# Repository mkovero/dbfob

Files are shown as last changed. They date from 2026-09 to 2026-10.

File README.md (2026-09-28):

# dbfob

**A dirt-cheap keyfob that tells you how loud it is — and how long your ears can take it.**

Press the button, look at the colour. Green means you're fine. Red means leave.

dbfob is an open-hardware sound level indicator sized for a keyring. It exists because nobody pulls out a phone on a dark dance floor to run a sound level meter, but everybody can glance at an LED. It is meant to be cheap enough that a venue, a festival or a hearing-health campaign can hand them out at the door next to the free earplugs.

## Status

**Rev A prototype, not yet validated on hardware.**

| Part | State |
|---|---|
| [Hardware](hardware/README.md) | 5 assembled boards ordered from JLCPCB, 2026-09-27. DRC-clean, placement verified against JLC's footprints. |
| [Firmware](firmware/README.md) | Builds for the CH32V003 and passes the host DSP tests (A-weighting within 0.02 dB, 50 Hz–8 kHz). Not yet run on a board. |
| [Case](hardware/case/README.md) | Two-shell SLA case modelled, fit-checked and exported. Not yet printed. |

Next steps are bring-up and calibration against a reference meter. See [Next](#next).

## How it works

1. Press the button. The fob wakes from standby.
2. A PDM MEMS microphone samples the room for 3 seconds.
3. The firmware A-weights the signal and computes the equivalent continuous level (LAeq).
4. A four-LED bar shows two verdicts for 2 seconds: a steady LED for a bare ear and a blinking LED for ear plugs. See below.

The LEDs are deliberately dim, since clubs are dark, and they auto-dim using one LED as a light sensor. Each reading is also printed on a UART pad for calibration.

### Colour bands

The bands are **levels at the ear**, not safety guarantees. The times are the full daily allowance at that level under the NIOSH / EU occupational curve, `T = 8 h × 2^((85 − L)/3)`: 85 dBA for 8 hours, 3 dB exchange rate.

| Colour | At the ear (dBA) | Daily allowance at that level |
|---|---|---|
| Green | ≤ 83 | Below the 85 dBA / 8 h limit |
| Yellow | 84–90 | About 10 h down to 2.5 h |
| Orange | 91–96 | About 2 h down to 40 min |
| Red | ≥ 97 | Under about 30 min |

A 3-second spot reading describes the room right now, not your night. The allowance is for a whole day starting from zero, so anything you've already heard today uses part of it. Green means this level is below the limit, not that the whole night is safe.

### Two LEDs, two questions

Every reading answers two questions at once, so there is no mode to set or forget:

- **Steady LED: what reaches a bare ear.** This is the room level itself: measured, with no assumptions.
- **Blinking LED: what would reach the ear through plugs that really give 12 dB.** This is a conditional estimate, not a measurement and not a safety verdict. The fob cannot know how well your plugs fit. Foam plugs claim 30+ dB on the box, but inserted in a hurry by someone who's had a drink, 10–15 dB is realistic. A badly seated plug can give much less. Individual fit testing is the only way to know your own attenuation, and NIOSH recommends it.

In a 100 dBA room, red glows steady and yellow blinks: you're in the red, and well-fitted plugs could bring you to yellow. When both answers are the same, only one steady LED lights.

The obvious alternative was a mode switch, but either default misleads someone. Assume plugs, and people without them get a falsely reassuring answer. Assume no plugs, and people who do wear them always see red, so the device looks useless to the people doing the right thing. Showing both removes the default, and the gap between the two LEDs is itself the argument for plugs.

### Modes

- **Single press — spot check.** Measures the current level and shows a colour for a few seconds. This is the mode that is always trustworthy, because you are holding the device out in front of you.
- **Double press — dosimeter.** *Not implemented; an idea for later.* The fob would sample for a couple of seconds every minute and accumulate dose. A single press would then show dose as a fraction of the daily allowance, bare ear and with plugs the same way.

The catch is that a keyfob lives in a pocket. A pocket reads 10–20 dB low with the high end rolled off, so an unsupervised dose would be a comforting lie. Dosimeter mode would need to detect occlusion from the spectrum, since the high-band to low-band energy ratio collapses in a pocket. It would refuse to count those samples and flag the dose as incomplete. For a real dosimeter, clip it to your shoulder.

## Hardware

No radio, no display, no app. The design goal was **under €2 all-in**. The rev A parts come to about $1.85 per board at 1,000 units. A 130 dB-capable mic alone is about €1.2, so sub-€1 is out unless mic prices drop.

| Block | Part | Why |
|---|---|---|
| Microphone | Infineon **IM69D130**, PDM | **Acoustic overload ≥ 130 dB SPL.** Hobby-favourite digital mics clip at about 120 dB, which a club sub stack exceeds. It is digital, with ±1 dB sensitivity, so a batch can be calibrated rather than each unit, and the reading doesn't drift with battery voltage. |
| MCU | WCH **CH32V003F4P6** | The CH32V002/V006 are pin-compatible drop-ins, but were out of stock. The V003 has no hardware multiplier (handled in firmware) and needs at least 2.7 V. |
| LEDs | 4 × 0603 low-Vf LEDs as a bar: yellow-green, yellow, orange, red | InGaN green and blue LEDs need about 3 V and fade on a coin cell. The bar position also encodes the level for colour-blind users. D4 doubles as the light sensor. |
| Power | CR2032 in a Keystone 3034 | Standby is about 7.6 µA, so an idle fob lasts about 3 years. The mic is powered only while measuring. |
| Input | 1 × tactile switch | Wakes the MCU. |
| Case | 3D-printed two-part shell, one M2 screw | Mic and LEDs at one end, keyring at the other. |

Background and trade-offs:
- The part comparison is in [docs/mic-mcu-options.md](docs/mic-mcu-options.md).
- An independent hardware audit, with the response to each finding, is in [docs/hardware-audit-2026-09-27.md](docs/hardware-audit-2026-09-27.md).

### Accuracy

Cheap MEMS parts are ±3 dB sensitivity; better ones are ±1 dB and factory-calibrated. Either is fine for four colour bands. The real uncertainty in this device is placement (held out vs. cupped in a hand vs. in a pocket) and earplug fit, not the microphone. Design effort goes into making "not trustworthy" visible, not into the last dB.

### Calibration

A 94 dB pistonphone won't couple to a MEMS port. Calibrate by substitution instead: place the fob next to a measurement mic in a room with pink noise at a few levels, note the offset, store it in flash. Also characterise the offset when hand-held vs. on a table, since that is how people will actually use it.

## Repository layout

```
hardware/        KiCad project, generated from the tables in hardware/tools/ (schematic, PCB, JLC outputs)
hardware/case/   FreeCAD case script, STEP/STL for printing, board geometry it is built from
firmware/        CH32V003 firmware on ch32fun: PDM capture, A-weighting, LAeq, LEDs, standby; host tests
docs/            part selection, hardware audit
```

## Next

- [ ] Bring-up on rev A: power, programming, mic capture, CPU load, standby current. See [firmware/README.md](firmware/README.md#bring-up-checklist).
- [ ] Calibrate against a reference meter, in the case: the level offset and the hand-held offset.
- [ ] Qualify the battery: the supply voltage under load across cell charge and temperature, then set the cutoff.
- [ ] Print the case and check the tolerances, the button flexure and the mic seal.
- [ ] A calibration procedure anyone can repeat with a known-good meter.
- [ ] Rev B board: centre the mic port, add UART RX for a bootloader, CH32V002/V006 if in stock, possibly a power latch for shelf life.
- [ ] Dosimeter mode with occlusion detection.
- [ ] Get a batch into a venue and see if people use them.

## Non-goals

- Bluetooth, apps, logging to the cloud. The point is that nothing needs to be looked at except one LED.
- Certified measurement accuracy. This is a warning light, not a Class 1 meter.

## Why

Hearing damage is cumulative and irreversible, and the people most at risk are the ones who go out the most. Earplugs are cheap and effective, but people don't put them in unless they have a reason to. A colour that says "you are in the red" is a reason.

## License

Hardware: CERN-OHL-P. Firmware: MIT. Documentation: CC BY 4.0.

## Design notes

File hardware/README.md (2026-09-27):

# dbfob hardware, rev A

30 × 52.5 mm, 2 layers, all parts on the top side. It is powered by a CR2032, the only input is one button, and the only output is a four-LED bar. Part choices are explained in [../docs/mic-mcu-options.md](../docs/mic-mcu-options.md).

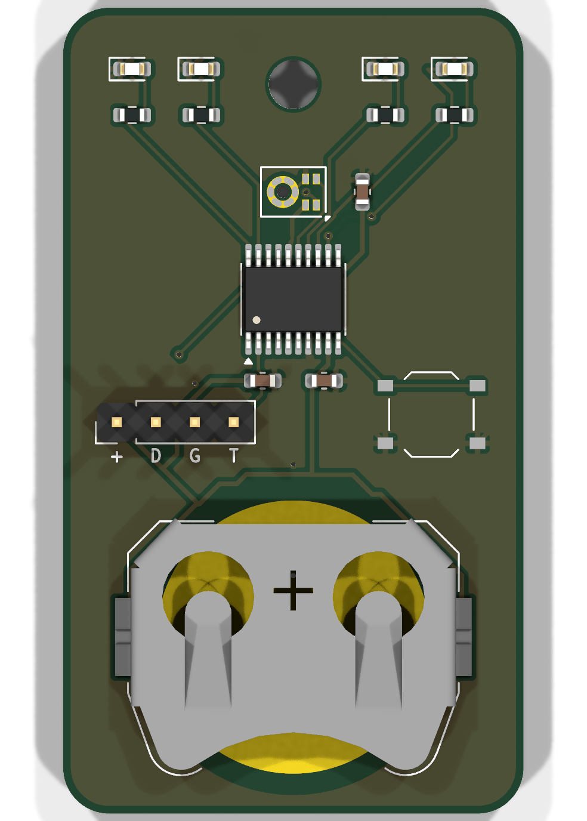
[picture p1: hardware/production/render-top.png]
top render


## Everything regenerates

The procedure follows `studer-vca/etofab.md`. The tables in `tools/gen_sch.py` are the only source; do not hand-edit the sheet or the board.

```sh
python3 hardware/tools/gen_sch.py    # tables -> dbfob.kicad_sch
python3 hardware/tools/make_pcb.py   # schematic -> placed, routed, poured, DRC'd board (~30 s)
python3 hardware/tools/fab.py        # board -> production/
```

These need KiCad 10 (`kicad-cli` and the `pcbnew` Python module) and [KiCadRoutingTools](https://github.com/drandyhaas/KiCadRoutingTools) at `/home/mui/src/KicadRoutingTools` (override with `KRT=`).

State at commit:
- **ERC:** clean, apart from KiCad's library-table warnings and one expected `pin_to_pin` warning. That warning comes from the PWR_FLAG on MIC_VDD, which is powered by a GPIO.
- **DRC:** 0 errors, 0 warnings, 0 unconnected, 0 schematic-parity issues.
- **Reproducibility:** two runs give byte-identical boards.

## Circuit

| U1 pin | Port | Net | Function |
|---|---|---|---|
| 15 | PC5 | MIC_CLK | SPI1 SCK, the PDM clock: 1.5 MHz (see [clock plan](#pdm-clock-plan)) |
| 17 | PC7 | MIC_DATA | SPI1 MISO, the PDM data. MK1 SELECT is tied to GND |
| 16 | PC6 | MIC_VDD | GPIO push-pull. The mic is powered only while measuring (≈0.6 mA at 1.5 MHz). Discard audio until 50 ms after VDD *and* the clock are both running |
| 20 | PD3 | LED_G | TIM2_CH2, D1 yellow-green |
| 19 | PD2 | LED_Y | TIM1_CH1, D2 yellow |
| 14 | PC4 | LED_O | TIM1_CH4, D3 orange |
| 13 | PC3 | LED_R | TIM1_CH3, D4 red (anode side) |
| 12 | PC2 | LED_R_K | D4 cathode: drive low to light it; reverse-bias and time the decay to sense ambient light |
| 10 | PC0 | BTN | SW1 to GND. Use the internal pull-up; EXTI wakes the MCU from standby |
| 18 | PD1 | SWIO | Programming (WCH-LinkE) |
| 2 | PD5 | TX | USART1 TX: prints dB readings during calibration |

**LEDs.** The bar is deliberately dim: a club is dark and the fob should not light up the room. The resistors cap the current at about 0.45 mA (2.2 kΩ), or about 1 mA for the dimmer yellow-green (1 kΩ). Firmware uses PWM to go well below that indoors and shows the result for about 2 s.
- **Ambient light sensing.** D4's cathode is on PC2 rather than GND, so the red LED doubles as a light sensor. Reverse-bias it (PC3 low, PC2 high), switch PC2 to input, and time how long it takes to read low. Fast means bright, which lets the firmware tell a dark room from daylight.
- **Why these LEDs.** All four are low-Vf AlInGaP/GaP types (1.6–2.6 V), so every colour still lights near the end of the cell's life; InGaN green and blue LEDs need about 3 V.
- **Order.** The bar runs G Y · O R from left to right. The position of the lit LED also encodes the level, so the bar works for colour-blind users.

**J1** is four 2.54 mm pads: `+ D G T` = VBAT, SWIO, GND, TX. Fit a header by hand, or hold pogo pins against it. It is not assembled.

**Mic port.** MK1 is a bottom-port mic, so it hears through the 0.8 mm hole to the **back** of the board (marked MIC). Don't cover it, and give the case an opening there.

**Coin cell.** The Keystone 3034 uses a PCB pad as the − contact. The cell's + can wraps around onto the − face at the rim, so the top layer has no copper in the ring under the rim: only solder mask would stand between + and a GND pour. The − pad reaches ground through four vias inside the pad. There is no reverse-polarity protection; the holder only accepts the cell one way round.

## MCU: fitted with a CH32V003

The CH32V002 and CH32V006 had **zero stock at JLC/LCSC on 2026-09-27**, so the BOM carries the pin-compatible **CH32V003F4P6** (C5187096, 1035 in stock). The TSSOP-20 pinout is identical: it was checked against table 2-1 of the V002 datasheet. When stock returns, change the LCSC number in `gen_sch.py`. The board stays the same.

The V003 costs the project two things:
- **No hardware multiply.** Build the firmware for `rv32ec`, which runs on all three chips. The biquads cost more cycles but fit easily at 48 MHz.
- **Minimum supply of 2.7 V instead of 2.0 V.** How much of the cell that costs is **not known yet**. See [Power](#power-unqualified).

## PDM clock plan

The IM69D130 is specified only in four clock bands: 0.40–0.95, 1.05–1.9, 2.1–2.65 and 2.9–3.3 MHz (datasheet table 4). The CH32's SPI clock is its bus clock divided by a power of two, 2 to 256. The earlier plan of 1.024 MHz fell between two bands and could not be generated anyway.

The plan is **1.5 MHz**: 48 MHz / 32, or 24 MHz / 16 if the core runs at 24 MHz to save current. Decimating by 64 gives **23,437.5 samples/s**, so the audio bandwidth reaches about 11.7 kHz. The decimator and the A-weighting biquads are designed for exactly that rate. The mic's startup time (20 ms to ±0.5 dB, 50 ms to ±0.2 dB) counts from when both VDD and the clock are present (table 5).

Still to show on hardware: the V003 has no multiplier and 2 KB of RAM, so it must keep up with 1.5 Mbit/s of PDM continuously.

## Power (unqualified)

These are datasheet estimates. No board current has been measured yet.

- **Active.** The CH32V003 draws about 4–6 mA at 48 MHz (HSI), and the mic about 0.6 mA. A CR2032's internal resistance rises as it discharges and as it gets cold. With 50 Ω, 6 mA pulls a 3.0 V cell down to the V003's 2.7 V minimum, and the 10 µF cap bridges that for only about half a millisecond, not a 3 s measurement. The V003 can also run below its guaranteed range before its reset threshold trips.
  - Firmware runs the measurement at 24 MHz, and measures VDD under load against the internal reference throughout.
  - Below a cutoff with margin, it shows an explicit **invalid / battery** pattern instead of a level.
  - Qualification: log minimum VDD through acquisition and display, across cell state of charge and temperature, with real cells.
  - If usable capacity is too low, reconsider the MCU or supply in rev B.
- **Standby.** The V003's typical standby current is 7.6 µA (LSI off), about 67 mAh per year. That limits an idle fob to roughly 3 years on a 220 mAh cell, much more than self-discharge does. The CH32V002 would be worse, at 17.5 µA. The mic uses no standby current because it is unpowered. If shelf life matters, rev B could add a button-triggered power latch, so standby becomes a switch's leakage.

## Programming

J1 pin 1 is wired directly to the cell's + terminal. **Take the cell out before connecting a programmer or powering a board for calibration.** A WCH-LinkE supplying 3.3 V into an installed CR2032 would charge it, and Energizer allows 1 µA of reverse current at most. Put the cell back in afterwards. The legend on the back of the board says the same. A fixture should enforce this order, for example by physically blocking the holder. A board powered from its cell must be programmed with the programmer's supply pin unconnected.

## Ordering at JLCPCB

Upload `production/dbfob-gerbers.zip`, then for assembly `production/bom_jlc.csv` and `production/cpl_jlc.csv`.

- **PCB:** 2 layers, 1.6 mm, any colour, tented vias.
- **Finish: lead-free HASL for prototypes, ENIG for production.** At 5 boards ENIG took the PCBA order from €6.46 to €22 (2026-09-27) for little gain here. The mic's 0.45 mm pads on a 0.7 mm pitch solder fine on HASL, and the holder's spring presses the cell onto the slightly domed − pad. Choose lead-free rather than leaded HASL: these get carried on keyrings. At volume the ENIG premium per board shrinks, and its flat, non-oxidising battery contact becomes worth it.
- **Assembly:** economic, top side only, 15 placements, 12 BOM lines. J1 is not placed. Board cleaning: no.
- **Tooling holes.** On a 1×1 board without edge rails, JLC drills its tooling holes into the board itself, and ground copper covers almost all of both sides. In the placement review, check they stay clear of:
  - the cell's − pad and the copper-free ring around it,
  - the traces between the LEDs and U1,
  - the mic hole.

  If they don't, order a 1×1 panel with edge rails instead.
- **Extended parts:** U1, MK1, BT1, D1, D2 and D3 are extended. Each carries JLC's flat per-part setup fee regardless of quantity (etofab.md §7).
- **Low-stock lines to check before paying:**
  - MK1 IM69D130 (C536262): 614 in stock, about $3 each at small quantities.
  - D3 orange KT-0603O (C111340): 3979 in stock.
- **Placement is verified against JLC's own footprints.** JLC places each part with the EasyEDA footprint of its LCSC number. `tools/check_cpl.py` puts those footprints where the CPL says and checks three things: every pad lands on the KiCad pad of the same pin, MK1's port lands on the sound hole, and BT1's opening faces the board edge. `fab.py` refuses to finish if any check fails. The corrections are in `JLC_FRAME` in `fab.py`:
  - U1: +270°.
  - MK1: +90°, and the CPL point moves 0.13 mm, because EasyEDA's origin is not the package centre.
  - BT1: +180°. Its pads are symmetric but the opening is not.
  - LEDs: none. The cathode is on the left in both libraries, even though the pad numbers differ.

  Rev A's first CPL had MK1 turned 90° and BT1 backwards; this check is what caught it. Still glance at JLC's preview before paying.
- **MK1 is a MEMS mic with an open port.** Make sure the board is not water-washed after reflow.

## Microphone supply

On 2026-09-27, DigiKey lists IM69D130V01XTSA1 as *Active*. The [hardware audit](../docs/hardware-audit-2026-09-27.md) reports that Infineon marks this ordering code *not for new design*; I could not confirm that on Infineon's site. Either way, rev A is a prototype and limited-build decision. Before repeat production, confirm the status and either secure supply or move to a replacement. The TDK T5818 is 1.65–3.63 V, ±1 dB and 135 dB AOP in its 2.0–3.3 MHz mode. A replacement means revalidating the footprint, clock plan and signal processing.

## Release gates

`make_pcb.py` exits nonzero on any DRC error, open net, schematic-parity issue, or DRC warning other than the missing-library-table one. `fab.py` refuses to write anything unless ERC, DRC and parity are clean. The only exceptions are the library-table warnings and the documented MIC_VDD PWR_FLAG. It builds every output in `production.staging/`, runs `check_cpl.py` there, and only then replaces `production/`. `check_cpl.py` also requires the BOM and CPL designator sets to match, each designator to appear once, and each CPL layer to match the board side.

## Not verified yet

This is rev A and no hardware exists. Open items before calling it done:
- Continuous 1.5 MHz PDM acquisition and decimation on the V003 (no multiplier, 2 KB RAM).
- Weighted level accuracy across frequency, SPL, hand placement and battery state, and behaviour on overload.
- The mic's current when powered from a GPIO.
- Standby current, VDD under load across cell state (see Power), and so usable capacity and shelf life.
- Mechanical: cell insertion, removal and retention, keyring abrasion, sound-port occlusion in the hand and in the final case. The render has no 3D model for the mic.
- The hand-held level offset.

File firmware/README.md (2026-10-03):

# dbfob firmware

Firmware for the rev A board: a CH32V003F4P6 with an IM69D130 PDM mic. It is built on [ch32fun](https://github.com/cnlohr/ch32fun), included as a submodule.

**Status: builds and passes host tests, but has never run on hardware.** Every constant marked `BRINGUP` in `dbfob.c` is an estimate that must be set on the bench.

## What it does

1. The board sits in standby until the button (PC0) is pressed.
2. It senses ambient light through D4 to set LED brightness.
3. It powers the mic from PC6 and clocks it at **1.5 MHz**: SPI1 SCK on PC5, 48 MHz / 32.
4. It captures PDM from MISO (PC7) by DMA into a 128-byte ring. Each 64-byte half is processed in the DMA interrupt.
5. It discards 150 ms of mic start-up and filter settling, then integrates **3 s** of A-weighted energy. VDD is read under load every 50 ms throughout.
6. It shows two verdicts for 2 s (see the [top-level README](../README.md#colour-bands)):
   - **Steady LED:** bare ear.
   - **Blinking LED:** with plugs giving 12 dB.
   - **Alternating G/R:** invalid reading (battery below the cutoff, no samples, or DMA overrun).
7. It prints one line per reading on USART1 TX (PD5, J1 pin 4 "T", 115200 8N1), then returns to standby.

Example output line:

```
dbfob dBA=94.2 dBFS=-35.7 n=70313 peak=1873 pcm_peak=1510 overload=0 vdd_idle=3012 vdd_min=2941 light_us=38210 duty=112 cpu=31% overruns=0
```

## Signal chain

Everything below is in `src/dsp.c`. The same file is compiled into the firmware and into the host test.

| Stage | Rate | Implementation |
|---|---|---|
| PDM in | 1.5 Mbit/s | SPI RX-only master, CPOL 0 / CPHA 0 (SELECT = GND: DATA valid while CLK low, sampled on the rising edge) |
| CIC, order 4, R = 64 | → 23,437.5 S/s | Closed-form byte step: 4 table lookups per byte (`src/cic_tables.h`, in flash) |
| A-weighting | 23,437.5 S/s | 4 first-order high-pass sections (the A curve's real poles), then 1 biquad fitted to the rest: the 12,194 Hz pole pair, CIC droop, and matched-z error. Q13 constants. |
| Energy | per sample | Σ y², square by table (`SQ[]`), 64-bit accumulator |
| Level | once | Integer 10·log10, Q8 dB |

**No hardware multiplier.** The V003 has none, and at `-Os` GCC calls libgcc's software multiply for every constant multiply. `dsp.c` is therefore compiled at `-O2`, where constant multiplies become shifts and adds, and the one runtime multiply (the square) is a table lookup. `tools/check_hotpath.sh` fails the build check if a software multiply reappears in the capture path.

**Verified on the host** (`make test`, with UBSan on):
- The CIC matches a bit-by-bit reference exactly.
- The chain is within **0.02 dB of IEC 61672 A-weighting from 50 Hz to 8 kHz**, and 0.09 dB at 31.5 Hz and 10 kHz.
- It is linear to within 0.12 dB from −60 to −6 dBFS.
- At −3 dBFS it has headroom: the peak intermediate uses 53k of the 131k that the 32-bit products allow.
- The simulated mic is a 2nd-order sigma-delta modulator.

**CPU**, from `make bench`: **11.3 M RV32EC instructions per second of audio** (about 39 per byte, about 168 per sample). The V2A core needs roughly 1.2–1.5 cycles per instruction, so this estimates **28–35 % of 48 MHz**. The firmware measures the real ISR share and prints it as `cpu=`.

**Resources:** flash 10.1 KB of 16 KB, static RAM 256 B of 2 KB.

## Build

```sh
git submodule update --init         # ch32fun
make check                          # build + hot-path check + host DSP tests
make bench                          # optional: instruction count under qemu-riscv32
```

This needs `riscv64-elf-gcc` and `riscv64-elf-newlib` (Arch: `pacman -S riscv64-elf-gcc riscv64-elf-newlib`). The host tests also need `gcc`, `python3`, `numpy` and `scipy`, and `make bench` needs `qemu-riscv32-static`.

`make filters` regenerates `src/filters.h` and `src/cic_tables.h` from `tools/design_filters.py`. The script checks the quantized response against the A curve and fails if it is off by more than 1 dB.

## Flash

**Take the coin cell out first.** J1 pin 1 is wired straight to the cell's + terminal, and a programmer supplying 3.3 V would charge it (see [hardware/README.md](../hardware/README.md#programming)).

You need one programmer. minichlink detects either of these automatically.

| Programmer | J1 `+` | J1 `D` (SWIO) | J1 `G` |
|---|---|---|---|
| WCH-LinkE | 3V3 | SWDIO | GND |
| ESP32-S2 with [esp32s2-funprog](https://github.com/cnlohr/esp32s2-cookbook/tree/master/ch32v003programmer) | **3V3, never 5 V** (the mic's maximum is 3.6 V) | GPIO6, optional 10 kΩ pull-up to 3V3 | GND |

Setting up the ESP32-S2 (once):
1. Hold BOOT while plugging it in.
2. From `esp32s2-cookbook/ch32v003programmer`, flash the prebuilt firmware:
   ```sh
   uvx esptool --chip esp32s2 -p /dev/ttyACM0 -b 460800 --before=no_reset --after=no_reset \
     write_flash --flash_mode dio --flash_freq 80m --flash_size 4MB \
     0x1000 build/bootloader/bootloader.bin 0x8000 build/partition_table/partition-table.bin 0x10000 build/usb_sandbox.bin
   ```
3. Connect the S2's **native USB**: this is where the programmer appears, not the USB-UART port. It enumerates as USB HID `303a:4004` ("CNLohr ESP32-S2 CH32V003Programmer").
   - On a board with only a USB-UART connector, such as the **ESP32-S2-Saola-1**, whose micro-USB is a CP2102N, wire a second USB cable to the header: D− → GPIO19, D+ → GPIO20, GND → GND.
   - Leave that cable's 5 V unconnected, and keep powering the board from its micro-USB.
   - Press EN after wiring.
4. Install `ch32fun/minichlink/99-minichlink.rules` into `/etc/udev/rules.d/` for access without root.

Then `make flash`. The firmware stays awake for 3 s after reset, sweeping the LEDs, so the programmer can reattach later. In standby SWIO is not answering; press the button or power-cycle to get a window.

### Reading the output

| Build | Output on | Read with |
|---|---|---|
| `make flash` (normal) | UART TX on J1 `T`, 115200 8N1 | Any 3.3 V USB-UART, or the WCH-LinkE's built-in one |
| `make flash PRINTF=swio` (bring-up) | The SWIO wire itself | `make monitor`, through the same programmer, ESP32-S2 included. No USB-UART needed. |

In the SWIO build, each `printf` waits up to about 200 ms when nothing is listening, so use it for bench work, not on a fob running from its cell.

## Bring-up checklist

Work down this list in order and record the numbers in `hardware/README.md`.

1. **Before power.** Check VBAT to GND is not a short. Check part orientation against the placement review.
2. **First power, from the programmer with no cell.** Run `make flash PRINTF=swio && make monitor`, then look for the boot banner with `vdd=`. The LEDs sweep G Y O R dimly.
3. **Mic capture.** Press the button in a quiet room and check:
   - `n` is about 70,300 (3 s × 23,437.5).
   - `overruns=0`.
   - `cpu=` is recorded. The estimate is 28–35 %, and anything under about 70 % is fine.
   - `pcm_peak` is well below 58,982 (the overload flag).
4. **Level calibration.** Put pink noise at 85, 95 and 105 dBA from a reference meter at the same spot. Set `CAL_DB_Q8` from the mean difference, then repeat hand-held to get the hand-held offset.
5. **VDD reference.** Compare `vdd_idle` with a multimeter on VBAT and trim `VREFINT_MV`.
6. **Battery.** Feed J1 from a bench supply through about 30–50 Ω, to mimic a tired cell. Step down from 3.0 V and note where `vdd_min` crosses the V003's 2.7 V. Set `VBAT_MIN_MV` with margin and confirm the invalid pattern appears. Then repeat with real cells at different charge levels ([hardware/README.md § Power](../hardware/README.md#power-unqualified)).
7. **Light sense.** Record `light_us` in the dark, in room light and in daylight, then set `LIGHT_BRIGHT_US` and `LIGHT_DARK_US`. Check that the dark-room brightness (`DUTY_MIN`) is visible without lighting up the room.
8. **Standby current.** With the cell's path through a µA meter and the programmer disconnected, compare against the datasheet's 7.6 µA.

## Not done yet

- Storing calibration constants in flash, instead of setting them at compile time.
- Double-press dosimeter mode.
- Pocket (occlusion) detection.
- A clip heuristic beyond the PCM-peak flag, which is not validated as a safeguard.
- Logarithmic brightness mapping.

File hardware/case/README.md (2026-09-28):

# dbfob case, rev A

A two-part case (SLA by default, FDM possible) around the rev A board: a **front shell** and a **back shell**, held by **one M2 screw**. To change the cell, open the case: undo the screw, lift the front, slide the cell out of the bottom of the holder. The LEDs show through **open windows**.

**Ends.** The mic port and the LEDs are at the top end; the keyring is at the opposite, bottom end. A hand holding the fob by its keys therefore doesn't cover the mic. The screw uses the board's own Ø3.2 hole (H1) at the top end.

Inputs, both generated from the board so the case follows any layout change:
- `dbfob-board.step`, from `kicad-cli pcb export step --subst-models --drill-origin`. It has no 3D models for MK1 and SW1; their sizes come from the datasheets and are recorded in the JSON.
- `board_geometry.json`: part centres, bounding boxes and heights, and every hole.

Coordinates are in the board's fab frame: x to the right and y up from the board's bottom-left corner. z = 0 is the board's back face.

## Numbers

| Item | Value | Source |
|---|---|---|
| Board | 30 × 52.5 × 1.6 mm, R3 corners | layout |
| Tallest part | BT1 holder + cell, 4.0 mm above the board | KiCad STEP model |
| Other parts | SW1 1.5 (incl. plunger), MK1 / U1 1.2, LEDs 0.8 mm | datasheets |
| Clearance | SLA: 0.15 mm board to wall, 0.1 mm lip, 0.1 mm nub gap (FDM: 0.3 / 0.15 / 0.2); 0.5 mm above BT1 | `PROCESS` in `make_case.py` |
| Walls / floor / top | 1.6 / 1.2 / 1.2 mm | 4 perimeters at 0.4 mm |
| Outer size | SLA 33.5 × 62.25 × 8.9 mm | board + walls + keyring end |

## Features

- **Screw.** An M2 × 6 **button head** (ISO 7380) goes through H1 at (15, 47.5), the board's own hole, and clamps the board between two Ø6 bosses.
  - Back shell: Ø2.3 clearance hole, with a Ø4.2 × 0.8 mm counterbore. The back is only 1.6 mm thick there.
  - Front shell: Ø1.7 pilot, 4.5 mm deep. The screw engages 3.6 mm, and its tip stops 2.1 mm short of the front face.
- **Keyring.** A Ø3.6 hole through both shells at the bottom end, (15, −4.2). The case extends 8 mm below the board to carry it.
  - It leaves 2.0 mm of material to the outer edge and 2.25 mm to the board pocket.
  - It's the end the cell comes out of, but the case is opened to change the cell anyway.
  - The mic port is not routed to an edge: a 13 mm duct to the top edge would resonate at about 6.6 kHz, inside the measured band.
- **Board retention.** The board is located by its outline pocket and the screw through H1.
  - It is clamped by 1 mm edge ribs from the front shell.
  - The ribs stay clear of J1's pads (x < 2.2 on the left) and BT1's tabs (x 3.1 and 26.9, y 8.9–14.1).
- **LED windows.** 1.4 × 1.0 mm openings over D1–D4 at x = 4.5, 9, 21, 25.5, y = 48.5.
  - Each sits at the top of a square light tube that stops 0.2 mm above the LED, so there is no bleed between LEDs and the light stays directional.
  - Small engraved G Y O R marks sit below the windows.
- **Button.** A flexure tongue in the front over SW1 at (24, 26).
  - It is a U-slot 0.6 mm wide, 12.5 × 9 mm, hinged towards the board centre, 8 mm from the nub, and thinned to 0.8 mm.
  - The hinge strain at full travel is 0.66 % (3·t·d / 2L²). The first draft's 4.5 mm hinge came to 2.7 %, which would have cracked in resin.
  - A Ø2.5 nub stops 0.1 mm (SLA) above the plunger.
- **Mic port.** A straight Ø1.0 hole in the back, directly under the board's sound hole at (14.32, 40.5), inside a Ø3 × 0.4 mm recess so a fingertip doesn't seal it.
  - It sits 0.68 mm off the case centreline. That's deliberate: the IM69D130's port is off its package centre and the board is fixed. Centring it would need a cavity joining two holes, with the gasket crossing a via.
  - Inside, a gasket ring (cavity Ø1.2, wall 0.5 mm, outer radius 1.1 mm) meets the board's back face, so sound reaches the mic only through the port. The ring clears the nearby tented SWIO via at (15.83, 40.47) by 0.11 mm.
  - On SLA the ring carries a 0.3 mm crush bead standing 0.08 mm proud (0.128 mm³ of intended interference); the board is preloaded onto it and the port is sealed.
  - The port's resonance is estimated at 35–40 kHz, well above the band measured.
- **Back floor.** It stands 0.4 mm off the board on a perimeter ledge and the gasket ring. The back of the board is flat: GND pour and tented vias only.

## Open until the first print

- Tolerances: the board pocket, the screw pilot, and the flexure's stiffness and travel.
- Whether the gasket ring seals well enough, measured as the level difference with the hole open and taped.
- The case's acoustic effect on the reading. The hand-held calibration from the firmware bring-up is done **in the case**.

## Files and printing

| File | What |
|---|---|
| `make_case.py` | The source: a FreeCAD script that builds both shells from `board_geometry.json`, checks fit and exports |
| `dbfob-case-back.stl` / `.step` | Back shell, floor down: 33.5 × 62.25 × 4.0 mm (SLA build) |
| `dbfob-case-front.stl` / `.step` | Front shell, top down: 33.5 × 62.25 × 5.7 mm (SLA build) |

The committed files are the **SLA** build, with `PROCESS = 'sla'`. For FDM, set `PROCESS = 'fdm'` and re-export. That opens up the clearances and drops the crush bead, since FDM layer lines would not seal against it anyway.

**SLA printing:**
- **Resin: use a tough, ABS-like resin**, not standard resin. Standard resin is brittle, and the flexure hinge and the thread-forming screw would crack it.
- **Orientation and supports:** the files are exported flat, but let the slicer tilt them about 30–45° with supports on the **inside** faces only. Keep supports off:
  - the front's top face and LED windows,
  - the back's outer face,
  - the crush bead,
  - the lip.
- **Post-cure:** fully, before assembly. Resin shrinks by about 0.5–1 % on curing; if the board pocket comes out tight, scale X/Y by +0.5 % in the slicer rather than re-cutting clearances.
- **Screw:** M2 × 6 button-head (ISO 7380) thread-forming screw into the Ø1.7 pilot. Don't overtighten into resin. Heat-set inserts don't work in thermoset resin.

Fit check on rev A (SLA):
- Front shell vs board, front shell vs parts, and front vs back: 0 mm³ overlap in each case.
- Back shell vs board: overlap is exactly the crush bead's intended 0.128 mm³, and nothing else.
- The gasket stays clear of the via.

### Regenerating

Run `make_case.py` in FreeCAD. The script only reads `board_geometry.json` from its own folder. Refresh that file from the board first if the layout changed; see the git history for the generator snippet.

`export(doc, out_dir)` writes the four files. On this project FreeCAD runs on a desktop with its MCP RPC port reverse-tunnelled to the dev machine. The exports come back with `scp -i ~/.ssh/id_free`, and are checked by SHA-256 against the desktop copies.

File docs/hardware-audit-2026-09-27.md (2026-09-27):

# Hardware and production audit — 2026-09-27

Audited revision: `d752502` (rev A). The starting worktree was clean. This audit adds only this report; all rebuilds and negative tests used copies under `/tmp/dbfob-audit`.

The committed PCB passes electrical connectivity, geometric DRC, schematic parity, and the existing placement check. Its manufacturing outputs agree with the board. It is suitable for prototype bring-up, but the clock specification, power qualification, product claims, and release checks need work before production release. No physical hardware or firmware was available for functional validation.

P1 means resolve before production use; P2 means a material production or maintenance risk to resolve before a repeatable release.

1. **P1 — The specified PDM clock is unsupported by the selected microphone and MCU clock plan.**

   Location: [hardware/README.md](../hardware/README.md), line 28; [docs/mic-mcu-options.md](mic-mcu-options.md), “Next steps”.

   The design specifies 1.024 MHz, decimation by 64, and 16 kHz audio. Infineon's operating bands stop at 950 kHz and resume at 1.05 MHz, so 1.024 MHz sits in an unspecified transition band. WCH's SPI divider is a power of two from 2 through 256; the fitted board's nominal 48 MHz internal clock cannot generate 1.024 MHz through it. Implementing the documented configuration therefore either uses an unspecified microphone clock or produces a different sample rate, invalidating filter coefficients designed for 16 kHz.

   Choose an attainable clock inside a specified band, then define the actual sample rate, decimator, and A-weighting coefficients together. For example, 48 MHz / 32 gives 1.5 MHz; decimation by 64 gives 23,437.5 samples/s. This example still needs processing and acoustic validation. Also count microphone startup delay from application of both supply and clock, not supply alone.

   Evidence: [Infineon IM69D130 datasheet, tables 4–5](https://www.infineon.com/assets/row/public/documents/24/49/infineon-im69d130-datasheet-en.pdf); [WCH reference manual, SPI_CTLR1 BR field](https://www.spinics.net/lists/trinity-users/attachments/pdfXz01Gp8QpG.pdf) (manufacturer document hosted on a mirror).

2. **P1 — The protected-ear verdict assumes protection the device cannot measure.**

   Location: [README.md](../README.md), lines 24–48; [hardware/tools/make_pcb.py](../hardware/tools/make_pcb.py), `SILK_B`.

   Subtracting 12 dB for every wearer can show blinking green at a room level of 95 dBA even when poorly fitted plugs provide substantially less attenuation. Calling that subtraction conservative does not establish a lower bound on protection. Showing the bare-ear LED simultaneously does not fix the meaning of the protected-ear verdict. NIOSH now recommends individual quantitative fit testing to determine received attenuation.

   The time labels also exceed what a three-second spot measurement establishes. Under the stated 85 dBA / 8 h / 3 dB curve, 96 dBA corresponds to about 38 minutes for a full daily dose, rather than an hour; previous exposure reduces the remaining allowance. A spot measurement cannot establish that an entire night is safe.

   Define the blinking result explicitly as a conditional estimate for a stated, verified attenuation, or remove the protected-ear safety verdict. Replace unconditional safety and remaining-time claims with level/risk indications. Update the PCB legend consistently before release.

   Evidence: [NIOSH individual fit-testing recommendation](https://www.cdc.gov/niosh/docs/2025-104/); [NIOSH exposure limits and exchange rate](https://www.cdc.gov/niosh/bulletin/2016/noise.html). Calculation: `T = 8 × 2^((85 − L)/3)` hours.

3. **P1 — The coin-cell capacity estimate ignores the supply margin during measurement.**

   Location: [hardware/README.md](../hardware/README.md), line 57; [hardware/tools/gen_sch.py](../hardware/tools/gen_sch.py), U1, C2, and BT1.

   The claim that switching to the V003 loses only the final 10–15% of capacity is unsupported for this load. The MCU requires at least 2.7 V and its documented 48 MHz HSI run current is approximately 4.0–6.4 mA before adding the microphone. Energizer characterizes a comparable 6.8 mA pulse at 2.7 V; its headline capacity is measured at approximately 0.19 mA down to 2.0 V. Those are different operating conditions.

   A 3.0 V cell with 50 ohms of effective source resistance reaches 2.7 V at 6 mA. The ideal 10 uF capacitor supports that current through a 0.3 V drop for only 0.5 ms, not the three-second acquisition. This establishes a qualification risk, not a measured failure of this PCB. The MCU can also remain out of its guaranteed operating range before its internal reset threshold is reached.

   Qualify actual cells across state of charge and intended temperature, logging minimum VDD throughout acquisition and display. Define an under-load battery cutoff with margin and an explicit invalid-reading state. Reconsider the MCU/supply if usable capacity is insufficient. Standby budgeting also needs revision: the documented typical 7.6 uA is about 66.6 mAh/year, before other leakage, so self-discharge alone does not set shelf life.

   Evidence: [WCH datasheet, supply/current/reset tables](https://www.jc-net.co.jp/pdf/CH32V003DS0-EN.pdf) (manufacturer document hosted on a mirror); [Energizer CR2032 datasheet](https://data.energizer.com/pdfs/cr2032.pdf). These are datasheet estimates; board current remains unmeasured.

4. **P2 — ERC/DRC are not enforced as production release gates.**

   Location: [hardware/tools/make_pcb.py](../hardware/tools/make_pcb.py), lines 347–383; [hardware/tools/fab.py](../hardware/tools/fab.py), lines 70–104.

   `make_pcb.py` prints remaining DRC errors, open nets, and parity violations, then returns normally. It also drops every library-footprint mismatch rather than distinguishing missing library configuration from a changed footprint. `fab.py` performs no ERC, DRC, or parity preflight and writes the Gerber ZIP before checking the CPL. Consequently, a later broken design can still produce an apparently successful, uploadable release.

   Reproduced with an isolated harness: supplying one `shorting_items` error to the final check printed `errors: 1` and returned normally. This was a control-flow test, not a short in the committed PCB.

   Make unresolved electrical/geometric/parity failures return nonzero. Allow only specifically justified warnings. Run preflight from the fabrication entry point, write into a staging directory, and publish the release files only after all checks pass.

5. **P2 — The CPL validator accepts missing parts and incorrect assembly sides.**

   Location: [hardware/tools/check_cpl.py](../hardware/tools/check_cpl.py), lines 73–108.

   The checker iterates only over CPL rows; it does not require each BOM reference to appear exactly once, and it never checks the `Layer` field. In independent copies, deleting U1's CPL row returned status 0. Restoring U1 and changing only its layer to `Bottom` also returned status 0 and printed `ok U1`.

   Require exact BOM/CPL reference-set equality, unique designators, and agreement between CPL layer and PCB footprint side before checking geometry. The current committed files have all 15 intended placements on Top, so these are validator defects rather than a present placement omission.

6. **P2 — The programming interface needs an explicit battery-isolation procedure.**

   Location: [hardware/tools/gen_sch.py](../hardware/tools/gen_sch.py), lines 62–70; [hardware/README.md](../hardware/README.md), line 45.

   J1 pin 1 and the CR2032 positive contact share VBAT without isolation. Connecting a powered programming fixture while a cell is installed therefore connects the fixture supply directly across the cell. A fixture voltage above the cell voltage can charge it; the Energizer specification allows only 1 uA reverse charge. The current programming instructions do not require battery removal or distinguish power output from voltage sensing.

   Specify programming and powered calibration with the battery removed, insert the battery afterward, and make the fixture enforce that sequence. If powered servicing with a cell present is required, add a suitable isolation arrangement. Verify the chosen programmer's power and signal voltages as part of the fixture specification.

   Evidence: schematic net assignment and [Energizer CR2032 reverse-charge limit](https://data.energizer.com/pdfs/cr2032.pdf).

7. **P2 — The selected microphone has a lifecycle risk absent from the production decision.**

   Location: [hardware/tools/gen_sch.py](../hardware/tools/gen_sch.py), lines 52–55; [docs/mic-mcu-options.md](mic-mcu-options.md), “Decision”.

   Infineon currently marks the exact `IM69D130V01XTSA1` ordering code as **not for new design**. Distributor stock alone is insufficient evidence for repeat production. This does not mean existing stock is unusable, but it needs an explicit prototype/limited-build decision and supply plan, or a supported replacement with its footprint and signal processing revalidated.

   Evidence checked 2026-09-27: [Infineon IM69D130 product status](https://www.infineon.com/part/IM69D130). Live distributor stock and assembly pricing were not rechecked in this audit.

**Checks completed**

| Check | Result |
|---|---|
| KiCad version | 10.0.6 |
| ERC, all severities | No errors; 37 missing-library configuration warnings and the documented GPIO/PWR_FLAG warning |
| PCB DRC, all track errors and schematic parity | No geometric errors, no open nets, no parity violations; 17 missing-footprint-library configuration warnings |
| Schematic regeneration | Byte-identical to the committed schematic |
| Complete PCB regeneration | Two independent runs produce byte-identical boards matching the committed board; the project also matches |
| Committed Gerbers and drills | Equal to fresh exports after excluding generation timestamps |
| Gerber ZIP | Exact member and byte agreement with the committed loose files |
| BOM/CPL membership | 12 BOM lines, 15 placements, matching designator sets |
| Existing CPL geometry check | All 15 placements pass, including mic port and battery-holder orientation |
| Drill inventory | Eleven 0.3 mm vias; four 1.0 mm header holes; 0.8 mm microphone port and 3.2 mm keyring NPTH |
| Visual inspection | Schematic PDF and top/bottom renders inspected |

The placed MCU's supply, SPI, UART, programming, LED timer pin assignments, and button EXTI capability agree with its datasheet. The microphone's pin assignment and 0.8 mm port agree with Infineon's documentation. No definite PCB wiring or placement defect was found. Missing library-table configuration prevents claiming a complete installed-library comparison. The schematic is electrically readable but several reference/value labels overlap symbols, and the long bottom note enters the title block.

**Remaining physical and firmware qualification**

The repository contains no firmware, programming image, measured acoustic results, or production test limits. Before release, demonstrate uninterrupted PDM acquisition and decimation within the fitted V003's 2 KB RAM and CPU budget; verify microphone supply/clock sequencing and GPIO supply voltage; compare weighted levels across frequency, SPL, placement, and battery conditions; test invalid-data/overload behavior; measure sleep current; and establish programming, LED/button, current, and acoustic acceptance checks. Define the measurement bandwidth explicitly: the proposed 16 kHz output cannot retain sound above 8 kHz.

The statement in `docs/mic-mcu-options.md` that microphone clipping necessarily appears as exact full-scale PCM samples is also unproven: acoustic overload is specified by distortion, and decimation can remove exact rail values. Do not treat that proposed detector as a validated safeguard. The same section still uses a 108 dBA top-band threshold, whereas the current bare-ear red threshold is above 96 dBA.

Prototype checks should include battery insertion/removal, polarity mistakes, retention, keyring abrasion, sound-port occlusion, and the final case's acoustic response. The current render lacks models for the microphone and switch, so it is not sufficient evidence for their assembled mechanical fit. The committed no-water-wash instruction should be carried into the assembly order. Cost and quantity targets also need a complete assembly quote; the repository's hobby-quantity goal and 1,000-unit BOM estimate are not equivalent.

---

## Response

Each finding was checked against the cited source before acting.

| # | Verdict | Resolution |
|---|---|---|
| 1 | Confirmed: bands 0.40–0.95 / 1.05–1.9 / 2.1–2.65 / 2.9–3.3 MHz, SPI divider powers of two | Clock plan is now 1.5 MHz (48/32 or 24/16), decimated by 64 to 23,437.5 samples/s, with filters designed for that rate. Startup is counted from VDD *and* clock. [hardware/README.md § PDM clock plan](../hardware/README.md#pdm-clock-plan) |
| 2 | Confirmed: 96 dBA gives 38 min | The bands are now levels at the ear, with allowance times computed from `T = 8·2^((85−L)/3)`. A spot reading is stated not to be a dose. The blinking LED is a conditional estimate "if plugs really give 12 dB", with a pointer to fit testing. The back legend now reads "blink = plugs IF 12 dB". |
| 3 | Confirmed: V003 standby 7.6 µA typ (the V002 is *worse*, at 17.5 µA) | The 10–15 % claim is withdrawn. [§ Power](../hardware/README.md#power-unqualified) lists the qualification plan, an under-load cutoff with an invalid state, the ~67 mAh/year standby budget, and a power latch as a rev B option. |
| 4 | Confirmed | `make_pcb.py` exits nonzero. Only `lib_footprint_issues` (missing library table) is allowed, so a footprint mismatch now fails. `fab.py` preflights ERC/DRC/parity and allows only the library-table warnings and the MIC_VDD PWR_FLAG. It stages every output and publishes only after `check_cpl.py` passes. |
| 5 | Confirmed, reproduced | `check_cpl.py` now requires equal BOM/CPL sets, unique designators, and CPL layer = board side. Negative tests (missing U1, U1 on Bottom, duplicated C1) now fail. |
| 6 | Confirmed | The documented procedure is to remove the cell before programming or bench power. That is added to the back silk ("REMOVE CELL TO PROGRAM"), the schematic notes and [§ Programming](../hardware/README.md#programming). |
| 7 | Unresolved | DigiKey lists IM69D130V01XTSA1 as *Active* on 2026-09-27; Infineon's page could not be read to confirm "not for new design". Recorded as a prototype/limited-build decision, with the T5818 as the replacement to revalidate. [§ Microphone supply](../hardware/README.md#microphone-supply) |
| Other | | Schematic notes moved clear of the title block. The unproven clip detector is marked a heuristic, not a safeguard. The stale 108 dBA threshold is corrected. The remaining physical and firmware qualification items are added to *Not verified yet*. |

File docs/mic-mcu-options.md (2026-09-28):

# Microphone and MCU options

The decision record for the microphone and MCU. The decision itself is at the top, followed by the survey that led to it. Rev A was built with this choice: see [hardware/README.md](../hardware/README.md).

Prices are LCSC / DigiKey list prices seen in September 2026, in USD. Check them again before ordering.

## Decision (2026-09-27)

- **Digital (PDM) microphone.** Analog is ruled out; see the cost and calibration comparison below.
- **AOP ≥ 130 dB SPL is a hard requirement.** 120 dB parts, including the cheap MSM261D series and the I2S hobby modules, are out. A clipping detector would only be an unvalidated sanity check (see below), never the safeguard.
- **Microphone: Infineon IM69D130.** AOP 130 dB SPL in *all* clock modes, including 768 kHz. −36 dBFS ±1 dB. Runs at 1.62–3.6 V, straight from a CR2032. About $1.38 at 1k.
  - Second source: **TDK T5818**. It is 1.65–3.63 V and ±1 dB, but it reaches 135 dB AOP only in high-quality mode (clock 2.0–3.3 MHz). Its low-power mode (400–800 kHz) drops to 120 dB. So on the T5818, firmware must run the clock at ≥2.048 MHz and decimate by 128. Keep the decimator's clock rate and decimation ratio configurable so either mic works.
- **MCU: WCH CH32V002.** Fall back to the CH32V006 if the internal op-amp or extra RAM is ever needed; it is pin-compatible. Not the CH32V003: it has no multiply and a 2.7 V minimum supply.
- PDM is read through SPI+DMA at 1.5 MHz, with software CIC/FIR decimation by 64 to 23,437.5 samples/s (see [hardware/README.md](../hardware/README.md#pdm-clock-plan)). An earlier draft said 1.024 MHz, but that falls between the mic's specified clock bands and cannot be divided from 48 MHz.
- **Rev A is fitted with the CH32V003F4P6.** The V002 and V006 had no JLC/LCSC stock on 2026-09-27, and all three share the TSSOP-20 pinout. See [hardware/README.md](../hardware/README.md#mcu-fitted-with-a-ch32v003).

### Prototype run (rev A), decided 2026-09-27

The prototype run uses the **CH32V003F4P6 and the IM69D130**. Both are in stock at JLC (1025 and 614 units). The V002/V006 are not in stock and the T5818 has none at JLC. The CPU estimate is about 36 % of 48 MHz (mic at 1.5 MHz, filtered down to 23,437.5 samples/s), and the DMA buffers need about 128 B of RAM. Both figures are rough, not measured. The run has to prove four things; if any fails, the fallback is the pin-compatible CH32V006 once stocked:

1. Continuous PDM acquisition, with the time per sample measured.
2. VDD under load across cell state and temperature.
3. Standby current.
4. Accuracy against a reference meter.

### T5818 as second source: clock and CPU

The T5818 holds 135 dB SPL only in high-quality mode, which needs a 2.0–3.3 MHz clock. Its low-power mode (400–800 kHz) clips at 120 dB. The CH32's power-of-two SPI divider reaches that band only at **3.0 MHz** (48/16 or 24/8); 1.5 MHz falls between the T5818's modes. The rates compared:

| | IM69D130 @ 1.5 MHz | T5818 @ 3.0 MHz |
|---|---|---|
| SPI + DMA bytes/s | 187.5 k | 375 k |
| Decimation | ÷64 → 23,437.5 S/s | ÷128 → 23,437.5 S/s |
| Decimator, byte lookup tables (est.) | ~6 % of 48 MHz | ~12 % |
| A-weighting, software multiply (est.) | ~30 % | ~30 % (same output rate, same coefficients) |
| Startup after VDD + clock | 20–50 ms | 7 ms |

The SPI and DMA themselves are not the limit. The cost of switching is:
- About 6 % more CPU for the decimator.
- A longer ÷128 filter, whose lookup tables are hard to fit in the V003's 16 KB of flash.
- A new footprint, since the T5818 is 3.5 × 2.65 mm.
- A new port position and new sensitivity constants (−41 dBFS against −36).

For either mic, the bigger lever is hardware multiply (CH32V002/V006), which would cut the A-weighting load to a few percent.

The survey below is kept for the record.

## Microphones

| Part | Type | AOP (dB SPL) | Sensitivity | VDD | Price | Notes |
|---|---|---|---|---|---|---|
| Goertek S15OT421-005 and similar | Analog | not checked (~120 typ.) | −38…−42 dBV, ±3 dB typ. | – | ~$0.09 | Also needs an op-amp (~$0.08) and passives, so ~$0.20 for the chain |
| TDK ICS-40618 | Analog, differential | **132** | ±1 dB | – | ~$1.80 (DigiKey qty 1) | Differential output, needs a real front end |
| MEMSensing MSM261DDB020 / DHT006 / DGT003 | PDM | 120 | −26 dBFS ±1 dB | 1.6–3.6 V | **$0.29–0.47** @1k, $0.58 qty 1 | 670 µA @ 2.4 MHz, 290 µA @ 768 kHz |
| **Infineon IM69D130** | PDM | **130** (<1 % THD to 128) | −36 dBFS ±1 dB | 1.62–3.6 V | ~$1.38 @1k, ~$2–3 qty 1 | 768 kHz / 1.536 / 2.4 / 3.072 MHz modes; the datasheet mentions "discotheque" as a use case |
| TDK T5818 | PDM | 135 (HQ mode) | ±1 dB | check | ~$1.2 @10k | Good parametric fallback |
| TDK T5838 | PDM | 133 (HQ mode) | −41 dBFS ±1 dB | **1.65–1.98 V** | $2.83 qty 1, $1.18 @10k | Needs an LDO. Poor fit for a coin cell |
| INMP441 / SPH0645 / ICS-43434 modules | I2S | ~120 | ±1 dB | 1.8–3.3 V | $1–2 module | Hobby favourites. I2S needs I2S hardware, so they don't fit the cheap MCUs |

### What AOP means for this device

The red band starts at 97 dBA at a bare ear, and rooms well above that are the point of the device. A bass-heavy room at that level can have unweighted peaks of 120–125 dB SPL, so a 120 dB AOP part clips in exactly the region where the answer matters most.

A firmware clip detector could catch some of this, for example by counting decimated samples near full scale and forcing red. That is unproven, though. AOP is defined by distortion, not a hard rail, and decimation filters smear or remove exact full-scale values. Treat it as a heuristic to validate, not a safeguard. This is why AOP ≥ 130 dB became a hard requirement. The error then always points toward warning: a very bassy 104 dBA room may read red instead of orange, but a genuinely red room never reads orange.

- **130+ dB AOP part (IM69D130):** correct bands everywhere. Costs ~$1 more.
- **120 dB AOP part (MSM261D):** correct up to orange, and the red band may show more often than it should. Costs ~$0.30.

Settled by the [Decision](#decision-2026-09-27): AOP ≥ 130 dB is a hard requirement, so the IM69D130.

## Analog vs digital: the price difference and what it means

### Cost

| | Analog | Digital (PDM) |
|---|---|---|
| Cheap tier | mic $0.06–0.09 + op-amp $0.08 + ~6 passives ≈ **$0.20** | mic ≈ **$0.30** + 1 decoupling cap |
| High-AOP tier | ICS-40618 $1.80 + front end | IM69D130 $1.38 |
| Board area / assembly | op-amp, gain network, bias, maybe 2 gain stages | 4 wires: VDD, GND, CLK, DATA (L/R tied) |

The difference is about **$0.10 at the cheap end and nothing at the high end.** It is the one place where spending a little more makes the device simpler.

### Calibration

Error sources in the analog chain, all of which add up per unit:

1. **Mic sensitivity:** ±3 dB on the $0.09 parts.
2. **ADC reference = VDD.** Cheap MCUs reference the ADC to the supply. A CR2032 sags from 3.0 V to about 2.2 V over its life, which moves the reading by `20·log10(3.0/2.2) ≈ 2.7 dB`. This can be fixed by measuring VDD against the internal bandgap on every press, but the bandgap is itself only accurate to a few percent.
3. **Dynamic range.** A 12-bit ADC gives 8–10 effective bits (~50–60 dB). Covering 80–130 dB SPL takes careful gain staging or two switchable gain ranges, and each range then needs its own calibration offset.
4. **Resistor and op-amp tolerance:** small, about 0.1–0.2 dB with 1 % parts.

With a PDM mic, error sources 2–4 go away. The mic's output is already digital, relative to its own full scale, and does not depend on the supply voltage. The IM69D130's ~105 dB dynamic range covers everything in one range. The only per-unit variable left is sensitivity, at **±1 dB**.

In practice, the colour bands are 6–7 dB wide:

- **Analog:** ±3 dB mic plus ±1–3 dB chain error. Every unit needs the substitution calibration from the README, stored in flash. That is a bench step per fob, which is the real cost at 1000 units.
- **Digital ±1 dB:** calibrate a *batch* instead. Characterise a few units for the hand-held offset and the frequency response, then flash the same constant into every unit. You can spot-check a sample from each reel.

The README's "calibration anyone can repeat" goal gets much easier. The procedure becomes a check that confirms a unit is within spec, not a step every unit must go through.

## MCUs

What the MCU has to do: run SPI with DMA as the PDM clock master (MISO = DATA), decimate 1-bit PDM at 1.5 MHz down to 23,437.5 samples/s, run three A-weighting biquads, sum squares for 3 s, then drive one LED. Byte-wise lookup-table CIC/FIR decimation (ST AN5027 / OpenPDMFilter style) costs roughly a few percent of a 24–48 MHz core. A hardware multiplier matters for the biquads.

| Part | Core | Hardware multiply | VDD min | SPI+DMA | Price | Notes |
|---|---|---|---|---|---|---|
| **CH32V002** | RV32EmC 48 MHz, 16K/4K | **yes** | **2.0 V** | yes | ~$0.10–0.15 | 12-bit 3 Msps ADC, pin-compatible with V003, QFN12…TSSOP20. Tooling: WCH-LinkE (~$4), ch32fun |
| CH32V006 | RV32EmC 48 MHz | yes | ~2.0 V | yes | ~$0.14–0.26 | Adds an internal op-amp (would matter only for an analog mic) |
| CH32V003 | RV32EC 48 MHz | **no** | 2.7 V | yes | ~$0.10 | No multiply, and dies well before the coin cell is empty. Skip it |
| PY32F002A/003 | Cortex-M0+ 24–32 MHz | yes | 1.7 V | yes | ~$0.08–0.15 | Cheapest and best low-voltage range. Thinner docs and toolchain |
| **STM32C011** | Cortex-M0+ 48 MHz | yes | 2.0 V | yes, plus I2S | ~$0.30–0.70 | Best docs (AN5027 covers PDM over SPI), any ST-Link, NUCLEO-C031C6 dev board. I2S also opens up the I2S mic modules |

**Pick: CH32V002.** It is cheap, has a hardware multiply, runs down to 2 V, and its toolchain and programmer are cheap and widely used by hobbyists. Firmware written for the V002 ports to the V006 or PY32 with little change. If the WCH ecosystem gets in the way during bring-up, move to the STM32C011: it costs ~$0.30 more and has the easiest debugging.

Power: see [hardware/README.md § Power](../hardware/README.md#power-unqualified). The V003's run current against a coin cell's internal resistance needs qualification, and its 7.6 µA standby current (the V002 is worse, at 17.5 µA), not self-discharge, sets shelf life at about 3 years.

## Estimated BOM (digital path, 1k qty)

| Item | Cheap | High-AOP |
|---|---|---|
| Mic | MSM261D $0.30 | IM69D130 $1.38 |
| MCU | CH32V002 $0.12 | CH32V002 $0.12 |
| RGB LED | $0.03 | $0.03 |
| Switch, caps, resistors | $0.05 | $0.05 |
| CR2032 holder | $0.05 | $0.05 |
| CR2032 cell | $0.10 | $0.10 |
| PCB | ~$0.10 | ~$0.10 |
| **Total** | **~$0.75** | **~$1.85** |

**Chosen: the high-AOP column, ~$1.85.** It meets the "under €2 all-in" goal at 1k. "Well under €1 at volume" is not reachable with a 130 dB mic at current prices, because the mic alone is ~$1.2–1.4. Accepted trade-off: correct red band > €1.

## Next steps

The breadboard stage was skipped: rev A went straight to assembled boards. Validation now happens on rev A itself, following the bring-up checklist in [firmware/README.md](../firmware/README.md#bring-up-checklist). That covers PDM capture at 1.5 MHz, CPU load, the level against a reference meter, no clipping at club levels, and the hand-held offset.

## Sources

- IM69D130 datasheet (Infineon): sensitivity −36 ±1 dBFS, AOP 130 dB SPL, VDD 1.62–3.6 V, clock modes
- [T5818 datasheet](https://media.digikey.com/pdf/Data%20Sheets/TDK%20PDFs/MMICT5818-00-012_DS.pdf): VDD 1.65–3.63 V, AOP 135 (HQ, 2.0–3.3 MHz) / 120 (LP, 400–800 kHz)
- MSM261DDB020 datasheet (LCSC C27636198): −26 ±1 dBFS, AOP 120 dB SPL, VDD 1.6–3.6 V
- [LCSC MSM261DHT006](https://www.lcsc.com/product-detail/C51928215.html) price breaks
- [DigiKey T5838](https://www.digikey.com/en/products/detail/tdk-invensense/MMICT5838-00-012/16903860), [T5818 highlight](https://www.digikey.com/en/product-highlight/i/invensense/t5818-pdm-microphone)
- [TDK ICS-40618](https://invensense.tdk.com/products/analog/ics-40618/)
- [Hackaday: audio input for 20 cents](https://hackaday.io/project/194511-1-dollar-tinyml/log/227784-audio-input-for-20-cents-usd) (analog chain costing)
- [CNX: CH32V002](https://www.cnx-software.com/2024/05/29/wch-ch32v002-32-bit-risc-v-mcu-comes-with-4kb-sram-supports-2v-to-5v-dc-supply-voltage/), [LCSC CH32V006](https://www.lcsc.com/product-detail/C52753342.html)
- [LCSC STM32C011F4P6](https://www.lcsc.com/product-detail/C5452432.html)
- [ST AN5027: PDM mics on STM32 over SPI](https://www.st.com/resource/en/application_note/dm00380469-interfacing-pdm-digital-microphones-using-stm32-mcus-and-mpus-stmicroelectronics.pdf)

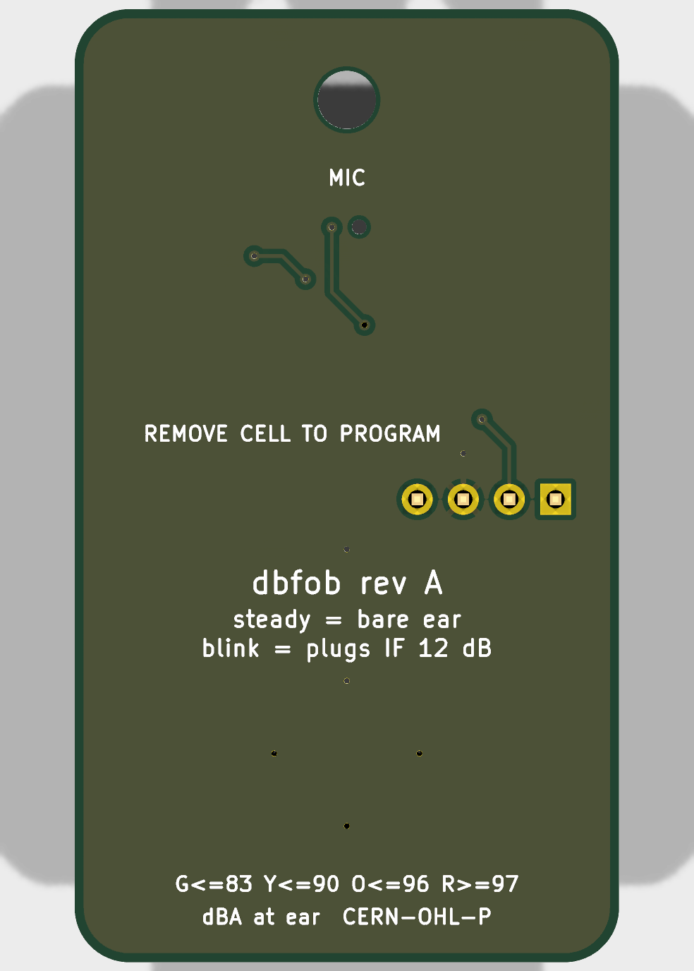
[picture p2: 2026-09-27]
hardware/production/render-bottom.png

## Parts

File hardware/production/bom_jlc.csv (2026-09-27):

Comment | Designator | Footprint | LCSC Part #
CR2032 Keystone 3034TR | BT1 | BatteryHolder_Keystone_3034_1x20mm | C5213768
100n CC0603KRX7R9BB104 | C1,C3 | C_0603_1608Metric | C14663
10u CL10A106KP8NNNC | C2 | C_0603_1608Metric | C19702
yellow-green 575nm NCD0603C3 | D1 | LED_0603_1608Metric | C89809
yellow 590nm KT-0603Y | D2 | LED_0603_1608Metric | C2287
orange 605nm KT-0603O | D3 | LED_0603_1608Metric | C111340
red 625nm KT-0603R | D4 | LED_0603_1608Metric | C2286
IM69D130 IM69D130V01XTSA1 | MK1 | Infineon_PG-LLGA-5-1 | C536262
1k | R4 | R_0603_1608Metric | C21190
2.2k | R5,R6,R7 | R_0603_1608Metric | C4190
measure TS-1187A-B-A-B | SW1 | SW_Push_1P1T_XKB_TS-1187A | C318884
CH32V003F4P6 CH32V003F4P6 | U1 | TSSOP-20_4.4x6.5mm_P0.65mm | C5187096

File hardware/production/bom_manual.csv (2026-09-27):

Designator | Value | MPN | Footprint | Note
J1 | PROG |  | PinHeader_1x04_P2.54mm_Vertical | not fitted: WCH-LinkE pogo/pins; 1 VBAT, 2 SWIO, 3 GND, 4 TX

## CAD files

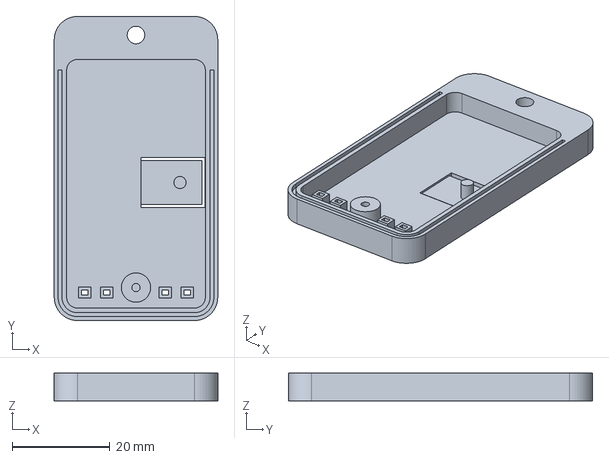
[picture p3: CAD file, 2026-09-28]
hardware/case/dbfob-case-front.step
33.5 x 62.2 x 5.70 mm

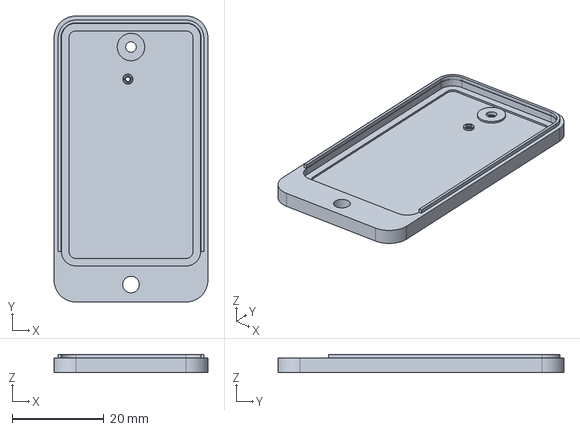
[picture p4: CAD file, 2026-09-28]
hardware/case/dbfob-case-back.step
33.5 x 62.2 x 4.00 mm

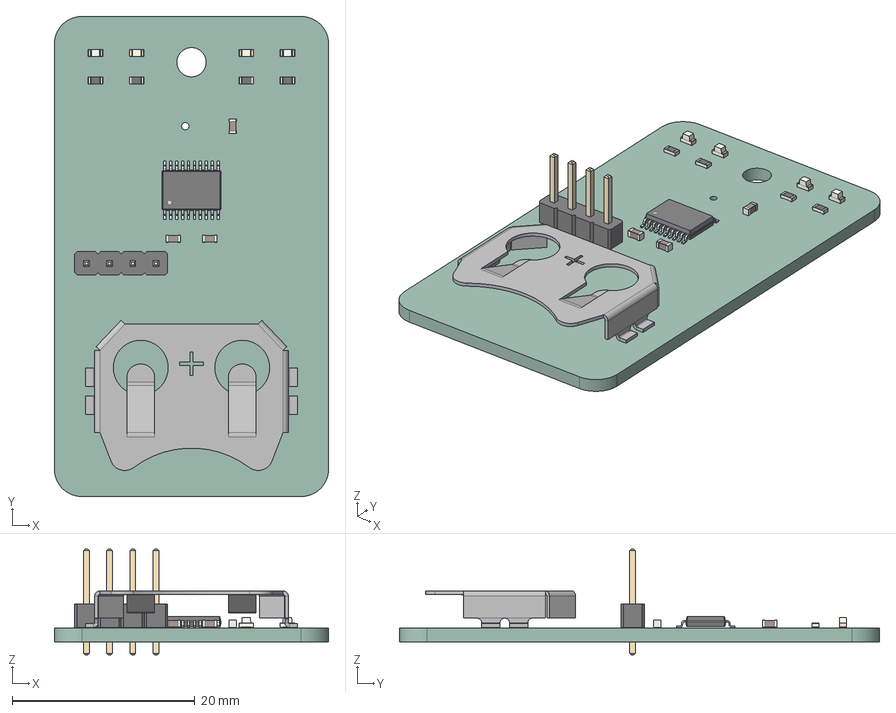
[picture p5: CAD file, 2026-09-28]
hardware/case/dbfob-board.step
30.0 x 52.5 x 11.5 mm
LED_0603_1608Metric x 4
C_0603_1608Metric x 3
BatteryHolder_Keystone_3034_1x20mm
R_0603_1608Metric x 4
PinHeader_1x04_P254mm_Vertical
TSSOP-20_4.4x6.5mm_P0.65mm
dbfob_PCB

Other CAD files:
hardware/case/dbfob-case-back.stl
hardware/case/dbfob-case-front.stl

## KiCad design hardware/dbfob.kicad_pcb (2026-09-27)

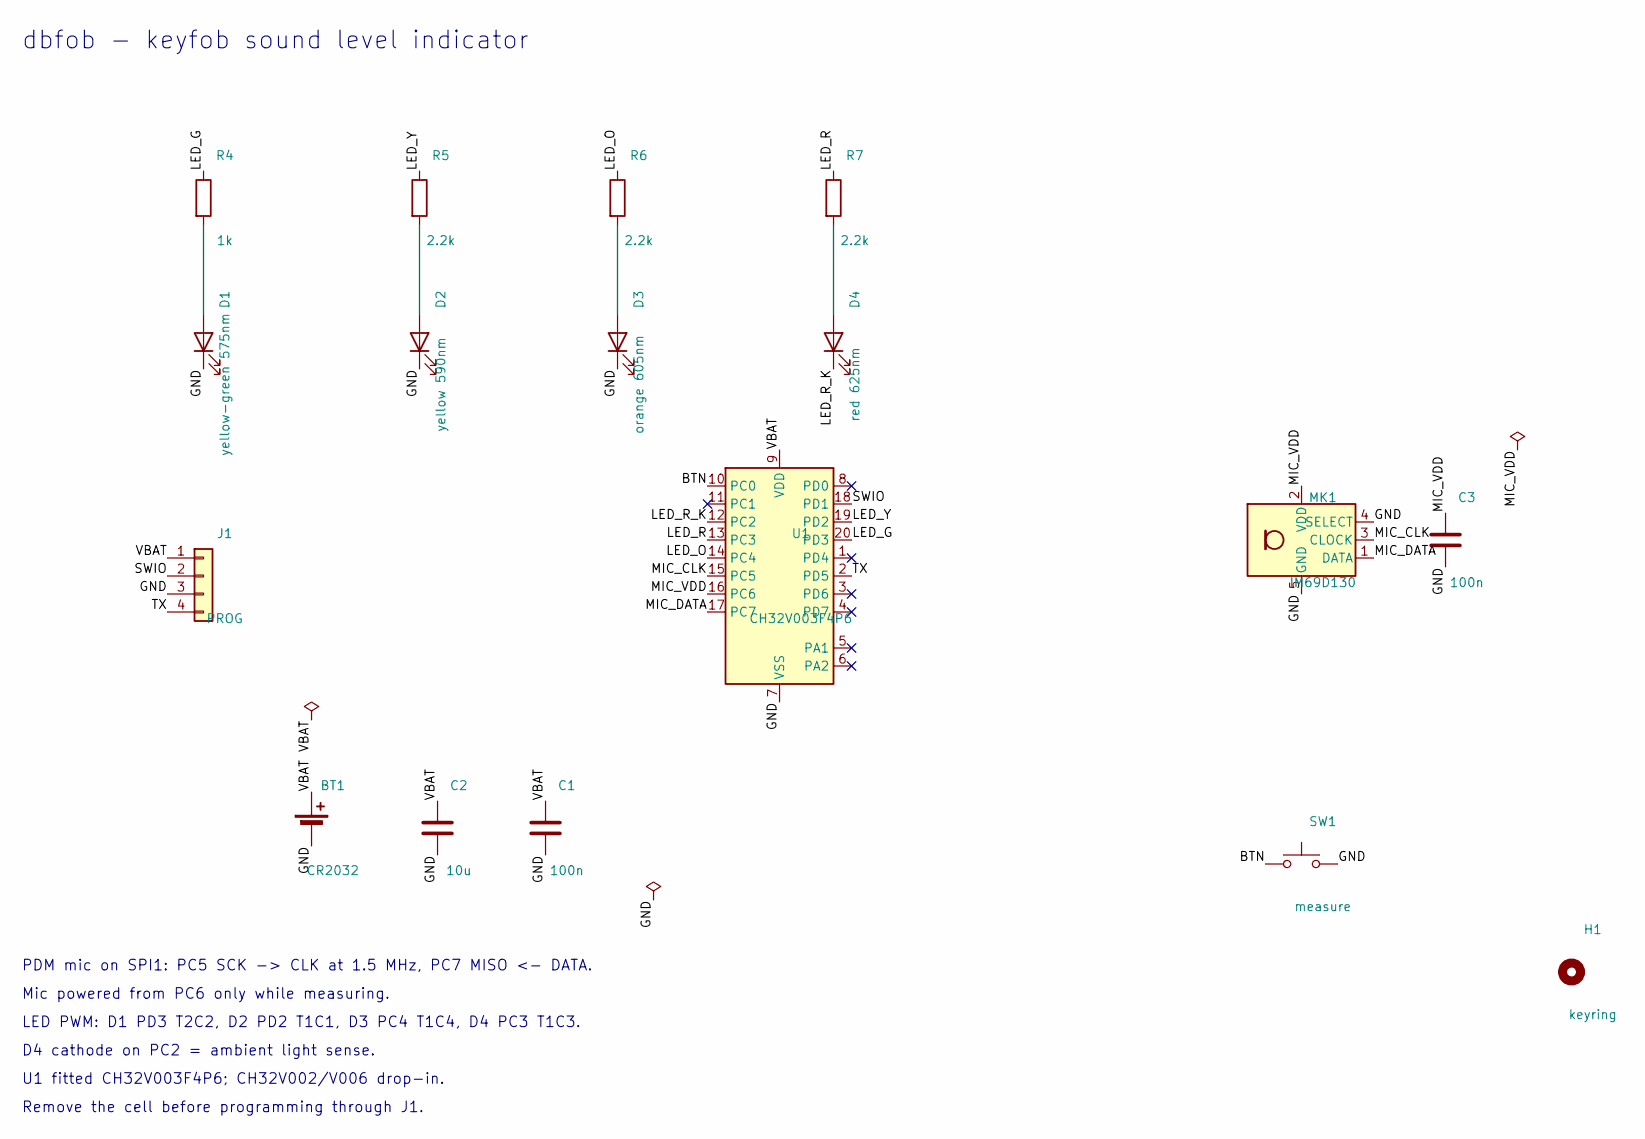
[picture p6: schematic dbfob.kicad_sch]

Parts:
BT1: CR2032; BatteryHolder_Keystone_3034_1x20mm; MPN Keystone 3034TR; LCSC C5213768
C1, C3: 100n; C_0603_1608Metric; MPN CC0603KRX7R9BB104; LCSC C14663
C2: 10u; C_0603_1608Metric; MPN CL10A106KP8NNNC; LCSC C19702
D1: yellow-green 575nm; LED_0603_1608Metric; MPN NCD0603C3; LCSC C89809
D2: yellow 590nm; LED_0603_1608Metric; MPN KT-0603Y; LCSC C2287
D3: orange 605nm; LED_0603_1608Metric; MPN KT-0603O; LCSC C111340
D4: red 625nm; LED_0603_1608Metric; MPN KT-0603R; LCSC C2286
H1: keyring; MountingHole_3.2mm_M3
J1: PROG; PinHeader_1x04_P2.54mm_Vertical
MK1: IM69D130; Infineon_PG-LLGA-5-1; MPN IM69D130V01XTSA1; LCSC C536262
R4: 1k; R_0603_1608Metric; LCSC C21190
R5, R6, R7: 2.2k; R_0603_1608Metric; LCSC C4190
SW1: measure; SW_Push_1P1T_XKB_TS-1187A; MPN TS-1187A-B-A-B; LCSC C318884
U1: CH32V003F4P6; TSSOP-20_4.4x6.5mm_P0.65mm; MPN CH32V003F4P6; LCSC C5187096

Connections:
/BTN: SW1.1, U1.10 (PC0)
/GND: BT1.2 (-), C1.2, C2.2, C3.2, D1.1 (K), D2.1 (K), D3.1 (K), J1.3, MK1.4 (SELECT), MK1.5 (GND), SW1.2, U1.7 (VSS)
/LED_G: R4.1, U1.20 (PD3)
/LED_O: R6.1, U1.14 (PC4)
/LED_R: R7.1, U1.13 (PC3)
/LED_R_K: D4.1 (K), U1.12 (PC2)
/LED_Y: R5.1, U1.19 (PD2)
/MIC_CLK: MK1.3 (CLOCK), U1.15 (PC5)
/MIC_DATA: MK1.1 (DATA), U1.17 (PC7)
/MIC_VDD: C3.1, MK1.2 (VDD), U1.16 (PC6)
/SWIO: J1.2, U1.18 (PD1)
/TX: J1.4, U1.2 (PD5)
/VBAT: BT1.1 (+), C1.1, C2.1, J1.1, U1.9 (VDD)
unnamed: D1.2 (A), R4.2
unnamed: D2.2 (A), R5.2
unnamed: D3.2 (A), R6.2
unnamed: D4.2 (A), R7.2

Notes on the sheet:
dbfob - keyfob sound level indicator
PDM mic on SPI1: PC5 SCK -> CLK at 1.5 MHz, PC7 MISO <- DATA.
Mic powered from PC6 only while measuring.
LED PWM: D1 PD3 T2C2, D2 PD2 T1C1, D3 PC4 T1C4, D4 PC3 T1C3.
D4 cathode on PC2 = ambient light sense.
U1 fitted CH32V003F4P6; CH32V002/V006 drop-in.
Remove the cell before programming through J1.

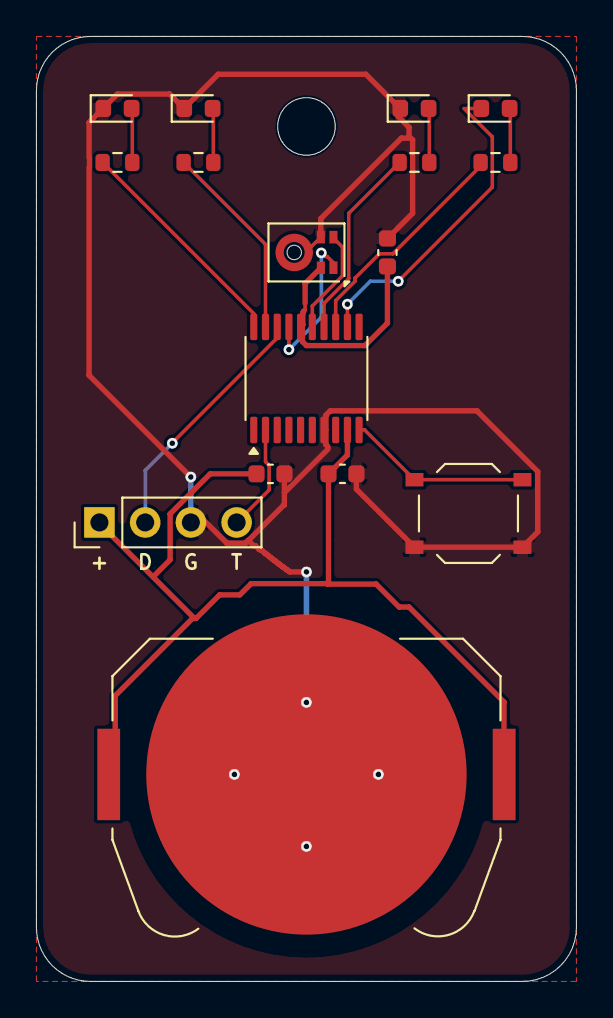
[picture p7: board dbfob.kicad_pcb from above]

Board: 2 copper layers, 30.0 x 52.5 mm, 17 parts (0 on the bottom side), 17 nets.

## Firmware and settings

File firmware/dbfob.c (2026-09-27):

// dbfob firmware, rev A board (CH32V003F4P6 + IM69D130).
//
// Press the button: the fob wakes from standby, powers the mic, captures 3 s of PDM over SPI1+DMA,
// A-weights it (src/dsp.c), and shows two verdicts on the LED bar for ~2 s: steady LED = bare ear,
// blinking LED = with plugs giving 12 dB. Then back to standby. Every reading is also printed on
// USART1 TX (PD5, J1 "T") for calibration against a reference meter.
//
// Pins (hardware/README.md):
//   PC5 SPI1 SCK  -> MIC_CLK   1.5 MHz (48 MHz / 32)
//   PC7 SPI1 MISO <- MIC_DATA  sampled on the rising edge (SELECT = GND: data valid while CLK low)
//   PC6 GPIO      -> MIC_VDD   mic powered only while measuring
//   PD3 TIM2_CH2 D1 G, PD2 TIM1_CH1 D2 Y, PC4 TIM1_CH4 D3 O, PC3 TIM1_CH3 D4 R (anodes via R)
//   PC2           D4 cathode: low = can light; high then input = ambient light sense
//   PC0           button to GND, EXTI0 wake
//
// NOT YET VALIDATED ON HARDWARE. Constants marked BRINGUP are estimates to set on the bench.
#include "ch32fun.h"
#include <stdio.h>
#include "dsp.h"

// ---- measurement -----------------------------------------------------------------------------
#define FS_OUT_HZ_X2      46875          // 2 x 23,437.5 S/s
#define MEASURE_MS        3000
#define SETTLE_MS         150            // mic start-up (<= 50 ms after VDD + clock) + filter settling
// IM69D130: -36 dBFS at 94 dB SPL, so 0 dBFS = 130 dB SPL. BRINGUP: trim by substitution
// against a reference meter, and add the hand-held offset (README.md "Calibration").
#define CAL_DB_Q8         (130 * 256)
#define PLUG_DB           12             // the blinking LED's assumed attenuation
// PCM peak above this fraction of full scale (after the CIC) = treat as overload -> red
#define OVERLOAD_PCM      ((DSP_FS * 9) / 10)

// ---- battery ---------------------------------------------------------------------------------
// The V003 is specified from 2.7 V. Below this under load the reading is refused. BRINGUP: set
// from the qualification in hardware/README.md "Power".
#define VBAT_MIN_MV       2800
#define VREFINT_MV        1200           // datasheet 1.17-1.23 V; BRINGUP: calibrate per board

// ---- display ---------------------------------------------------------------------------------
#define SHOW_MS           2000
#define BLINK_MS          250
#define PWM_TOP           999            // 48 kHz PWM
// light sense: D4 discharge time -> brightness. BRINGUP: both thresholds from bench readings.
#define LIGHT_BRIGHT_US   2000           // faster than this: daylight, full brightness
#define LIGHT_DARK_US     50000          // slower than this: dark room, minimum brightness
#define DUTY_MIN          10             // of PWM_TOP: dim enough for a dark club
#define DUTY_MAX          PWM_TOP

enum { LED_G, LED_Y, LED_O, LED_R, LED_NONE };

static volatile dsp_t dsp;
static uint8_t pdm[128];                 // DMA ring: two halves of 64 bytes = 8 output samples each
static volatile uint32_t isr_cycles, overruns;
static volatile uint8_t capturing;

// ---- PDM capture: SPI1 RX-only master + DMA1 channel 2 ---------------------------------------
void DMA1_Channel2_IRQHandler(void) __attribute__((interrupt));
void DMA1_Channel2_IRQHandler(void)
{
	uint32_t t0 = SysTick->CNT;
	uint32_t f = DMA1->INTFR;
	DMA1->INTFCR = DMA1_IT_GL2 | DMA1_IT_HT2 | DMA1_IT_TC2;
	if ((f & DMA1_IT_HT2) && (f & DMA1_IT_TC2)) overruns++;   // both halves done: we fell behind
	if (capturing) {
		if (f & DMA1_IT_HT2) dsp_feed((dsp_t *)&dsp, pdm, 64);
		if (f & DMA1_IT_TC2) dsp_feed((dsp_t *)&dsp, pdm + 64, 64);
	}
	isr_cycles += SysTick->CNT - t0;
}

static void mic_start(void)
{
	funDigitalWrite(PC6, FUN_HIGH);                          // MIC_VDD
	funPinMode(PC5, GPIO_CFGLR_OUT_50Mhz_AF_PP);             // SCK
	funPinMode(PC7, GPIO_CFGLR_IN_FLOAT);                    // MISO

	RCC->APB2PRSTR |= RCC_APB2Periph_SPI1;
	RCC->APB2PRSTR &= ~RCC_APB2Periph_SPI1;
	DMA1_Channel2->CFGR = 0;
	DMA1_Channel2->PADDR = (uint32_t)&SPI1->DATAR;
	DMA1_Channel2->MADDR = (uint32_t)pdm;
	DMA1_Channel2->CNTR = sizeof pdm;
	DMA1_Channel2->CFGR = DMA_Priority_VeryHigh | DMA_MemoryDataSize_Byte | DMA_PeripheralDataSize_Byte |
	                      DMA_MemoryInc_Enable | DMA_Mode_Circular | DMA_DIR_PeripheralSRC |
	                      DMA_IT_HT | DMA_IT_TC | DMA_CFGR1_EN;
	NVIC_EnableIRQ(DMA1_Channel2_IRQn);
	// CPOL 0 / CPHA 0: sample on the rising edge. RX-only master clocks continuously once enabled.
	SPI1->CTLR2 = SPI_CTLR2_RXDMAEN;
	SPI1->CTLR1 = SPI_NSS_Soft | SPI_CPHA_1Edge | SPI_CPOL_Low | SPI_DataSize_8b | SPI_FirstBit_MSB |
	              SPI_Mode_Master | SPI_Direction_2Lines_RxOnly | SPI_BaudRatePrescaler_32;
	SPI1->CTLR1 |= CTLR1_SPE_Set;
}

static void mic_stop(void)
{
	capturing = 0;
	SPI1->CTLR1 &= CTLR1_SPE_Reset;
	NVIC_DisableIRQ(DMA1_Channel2_IRQn);
	DMA1_Channel2->CFGR = 0;
	RCC->APB2PRSTR |= RCC_APB2Periph_SPI1;                   // RX-only master: reset is the clean stop
	RCC->APB2PRSTR &= ~RCC_APB2Periph_SPI1;
	funPinMode(PC5, GPIO_CFGLR_OUT_2Mhz_PP);
	funDigitalWrite(PC5, FUN_LOW);
	funDigitalWrite(PC6, FUN_LOW);                           // mic off: no standby current
}

// ---- VDD from the internal reference ---------------------------------------------------------
static void adc_init(void)
{
	RCC->APB2PCENR |= RCC_APB2Periph_ADC1;
	RCC->CFGR0 &= ~(0x1F << 11);                             // ADCCLK = HCLK / 2
	ADC1->RSQR1 = 0; ADC1->RSQR2 = 0;
	ADC1->RSQR3 = 8;                                         // channel 8: Vrefint
	ADC1->SAMPTR2 = 7 << (3 * 8);                            // longest sample time for Vrefint
	ADC1->CTLR2 = ADC_ADON | ADC_EXTSEL;
	Delay_Us(10);
	ADC1->CTLR2 |= ADC_RSTCAL; while (ADC1->CTLR2 & ADC_RSTCAL);
	ADC1->CTLR2 |= ADC_CAL; while (ADC1->CTLR2 & ADC_CAL);
}

static uint32_t vdd_mv(void)
{
	ADC1->CTLR2 |= ADC_SWSTART;
	while (!(ADC1->STATR & ADC_EOC));
	uint32_t raw = ADC1->RDATAR;
	return raw ? VREFINT_MV * 1023 / raw : 0;
}

// ---- LEDs: TIM1 CH1/3/4 + TIM2 CH2 PWM -------------------------------------------------------
static void leds_init(void)
{
	RCC->APB2PCENR |= RCC_APB2Periph_TIM1;
	RCC->APB1PCENR |= RCC_APB1Periph_TIM2;
	TIM1->PSC = 0; TIM1->ATRLR = PWM_TOP;
	TIM2->PSC = 0; TIM2->ATRLR = PWM_TOP;
	// PWM mode 1 with preload: TIM1 CH1 (PD2), CH3 (PC3), CH4 (PC4); TIM2 CH2 (PD3)
	TIM1->CHCTLR1 = TIM_OC1M_2 | TIM_OC1M_1 | TIM_OC1PE;
	TIM1->CHCTLR2 = TIM_OC1M_2 | TIM_OC1M_1 | TIM_OC1PE | ((TIM_OC1M_2 | TIM_OC1M_1 | TIM_OC1PE) << 8);
	TIM1->CCER = TIM_CC1E | TIM_CC3E | TIM_CC4E;
	TIM1->BDTR = TIM_MOE;
	TIM2->CHCTLR1 = (TIM_OC1M_2 | TIM_OC1M_1 | TIM_OC1PE) << 8;
	TIM2->CCER = TIM_CC2E;
	TIM1->CH1CVR = TIM1->CH3CVR = TIM1->CH4CVR = 0; TIM2->CH2CVR = 0;
	TIM1->SWEVGR = TIM_UG; TIM2->SWEVGR = TIM_UG;
	TIM1->CTLR1 = TIM_ARPE | TIM_CEN;
	TIM2->CTLR1 = TIM_ARPE | TIM_CEN;
}

static void leds_pins(void)
{
	funPinMode(PD3, GPIO_CFGLR_OUT_2Mhz_AF_PP);
	funPinMode(PD2, GPIO_CFGLR_OUT_2Mhz_AF_PP);
	funPinMode(PC4, GPIO_CFGLR_OUT_2Mhz_AF_PP);
	funPinMode(PC3, GPIO_CFGLR_OUT_2Mhz_AF_PP);
	funPinMode(PC2, GPIO_CFGLR_OUT_2Mhz_PP);
	funDigitalWrite(PC2, FUN_LOW);                           // D4 cathode to ground
}

static void led_set(int which, uint32_t duty)
{
	TIM2->CH2CVR = which == LED_G ? duty : 0;
	TIM1->CH1CVR = which == LED_Y ? duty : 0;
	TIM1->CH4CVR = which == LED_O ? duty : 0;
	TIM1->CH3CVR = which == LED_R ? duty : 0;
}

// Two LEDs at once (steady + blinking) share the bar by alternating at the PWM level:
static void leds_two(int steady, int blink, int blink_on, uint32_t duty)
{
	TIM2->CH2CVR = (steady == LED_G || (blink_on && blink == LED_G)) ? duty : 0;
	TIM1->CH1CVR = (steady == LED_Y || (blink_on && blink == LED_Y)) ? duty : 0;
	TIM1->CH4CVR = (steady == LED_O || (blink_on && blink == LED_O)) ? duty : 0;
	TIM1->CH3CVR = (steady == LED_R || (blink_on && blink == LED_R)) ? duty : 0;
}

// ---- ambient light: D4 reverse-biased, time the photocurrent discharge ------------------------
static uint32_t light_us(void)
{
	funPinMode(PC3, GPIO_CFGLR_OUT_2Mhz_PP);                 // anode side (through R7) low
	funDigitalWrite(PC3, FUN_LOW);
	funDigitalWrite(PC2, FUN_HIGH);                          // cathode high: charge the junction
	Delay_Us(20);
	funPinMode(PC2, GPIO_CFGLR_IN_FLOAT);
	uint32_t t0 = SysTick->CNT, limit = (LIGHT_DARK_US * 2) * (FUNCONF_SYSTEM_CORE_CLOCK / 1000000);
	uint32_t dt;
	while ((dt = SysTick->CNT - t0) < limit && funDigitalRead(PC2));
	leds_pins();
	return dt / (FUNCONF_SYSTEM_CORE_CLOCK / 1000000);
}

static uint32_t duty_for_light(uint32_t us)
{
	if (us <= LIGHT_BRIGHT_US) return DUTY_MAX;
	if (us >= LIGHT_DARK_US) return DUTY_MIN;
	// geometric interpolation would be nicer; linear in log is BRINGUP work
	return DUTY_MIN + (DUTY_MAX - DUTY_MIN) * (LIGHT_DARK_US - us) / (LIGHT_DARK_US - LIGHT_BRIGHT_US);
}

// ---- verdicts --------------------------------------------------------------------------------
static int band(int32_t dba_q8)
{
	if (dba_q8 < (int32_t)(83.5 * 256)) return LED_G;         // <= 83
	if (dba_q8 < (int32_t)(90.5 * 256)) return LED_Y;         // 84-90
	if (dba_q8 < (int32_t)(96.5 * 256)) return LED_O;         // 91-96
	return LED_R;                                              // >= 97
}

static void show_invalid(uint32_t duty)                     // battery / invalid: G and R alternate
{
	for (int i = 0; i < 6; i++) { led_set(i & 1 ? LED_R : LED_G, duty); Delay_Ms(150); }
	led_set(LED_NONE, 0);
}

static void print_q8(const char *name, int32_t q8)
{
	int32_t a = q8 < 0 ? -q8 : q8;
	printf(" %s=%s%ld.%01ld", name, q8 < 0 ? "-" : "", (long)(a >> 8), (long)(((a & 255) * 10) >> 8));
}

static void measure_and_show(void)
{
	uint32_t light = light_us();
	uint32_t duty = duty_for_light(light);
	uint32_t v_idle = vdd_mv(), v_min = v_idle;

	dsp_reset((dsp_t *)&dsp, SETTLE_MS * FS_OUT_HZ_X2 / 2000);
	isr_cycles = 0; overruns = 0;
	capturing = 1;
	uint32_t t0 = SysTick->CNT;
	mic_start();
	for (uint32_t ms = 0; ms < SETTLE_MS + MEASURE_MS; ms += 50) {
		Delay_Ms(50);
		uint32_t v = vdd_mv();                                 // VDD under load, throughout
		if (v < v_min) v_min = v;
	}
	mic_stop();
	uint32_t total = SysTick->CNT - t0;

	int32_t dbfs = dsp_level_dbfs_q8((dsp_t *)&dsp);
	int32_t dba = dbfs + CAL_DB_Q8;
	int overload = dsp.pcm_peak >= OVERLOAD_PCM;
	int invalid = v_min < VBAT_MIN_MV || !dsp.n || overruns;

	printf("dbfob");
	print_q8("dBA", dba); print_q8("dBFS", dbfs);
	printf(" n=%lu peak=%ld pcm_peak=%ld overload=%d vdd_idle=%lu vdd_min=%lu light_us=%lu duty=%lu"
	       " cpu=%lu%% overruns=%lu%s\n",
	       (unsigned long)dsp.n, (long)dsp.peak, (long)dsp.pcm_peak, overload, (unsigned long)v_idle,
	       (unsigned long)v_min, (unsigned long)light, (unsigned long)duty,
	       (unsigned long)(total ? (uint64_t)isr_cycles * 100 / total : 0), (unsigned long)overruns,
	       invalid ? " INVALID" : "");

	if (invalid) { show_invalid(duty); return; }
	int bare = overload ? LED_R : band(dba);
	int plugs = overload ? LED_R : band(dba - PLUG_DB * 256);
	for (uint32_t ms = 0; ms < SHOW_MS; ms += BLINK_MS) {
		leds_two(bare, plugs == bare ? LED_NONE : plugs, (ms / BLINK_MS) & 1, duty);
		Delay_Ms(BLINK_MS);
	}
	led_set(LED_NONE, 0);
}

// ---- power -----------------------------------------------------------------------------------
static void pins_init(void)
{
	RCC->APB2PCENR |= RCC_APB2Periph_GPIOA | RCC_APB2Periph_GPIOC | RCC_APB2Periph_GPIOD | RCC_AFIOEN;
	// unused pins: pulled down, no floating inputs in standby
	funPinMode(PA1, GPIO_CFGLR_IN_PUPD); funDigitalWrite(PA1, FUN_LOW);
	funPinMode(PA2, GPIO_CFGLR_IN_PUPD); funDigitalWrite(PA2, FUN_LOW);
	funPinMode(PC1, GPIO_CFGLR_IN_PUPD); funDigitalWrite(PC1, FUN_LOW);
	funPinMode(PD0, GPIO_CFGLR_IN_PUPD); funDigitalWrite(PD0, FUN_LOW);
	funPinMode(PD4, GPIO_CFGLR_IN_PUPD); funDigitalWrite(PD4, FUN_LOW);
	funPinMode(PD6, GPIO_CFGLR_IN_PUPD); funDigitalWrite(PD6, FUN_LOW);
	// mic: unpowered, clock low, data pulled down (never drive a powered-down part's pins high)
	funPinMode(PC6, GPIO_CFGLR_OUT_2Mhz_PP); funDigitalWrite(PC6, FUN_LOW);
	funPinMode(PC5, GPIO_CFGLR_OUT_2Mhz_PP); funDigitalWrite(PC5, FUN_LOW);
	funPinMode(PC7, GPIO_CFGLR_IN_PUPD); funDigitalWrite(PC7, FUN_LOW);
	// button: pull-up, EXTI line 0 on port C, falling edge as a wake event
	funPinMode(PC0, GPIO_CFGLR_IN_PUPD); funDigitalWrite(PC0, FUN_HIGH);
	AFIO->EXTICR = (AFIO->EXTICR & ~(3u << 0)) | (2u << 0);   // line 0 <- port C
	EXTI->EVENR |= EXTI_Line0;
	EXTI->FTENR |= EXTI_Line0;
	leds_pins();
}

static void standby(void)
{
	RCC->APB1PCENR |= RCC_APB1Periph_PWR;
	PWR->CTLR |= PWR_CTLR_PDDS;
	PFIC->SCTLR |= 1 << 2;                                    // SLEEPDEEP
	__WFE();
	SystemInit();                                             // back to 48 MHz after wake
}

int main(void)
{
	SystemInit();
	pins_init();
	adc_init();
	leds_init();
	printf("\ndbfob rev A fw " __DATE__ " vdd=%lu\n", (unsigned long)vdd_mv());
	// Stay awake 3 s after reset so a programmer can attach before the first standby.
	for (int i = 0; i < 4; i++) { led_set(i, DUTY_MIN * 4); Delay_Ms(750); }
	led_set(LED_NONE, 0);
	for (;;) {
		standby();
		Delay_Ms(20);                                         // debounce
		if (funDigitalRead(PC0)) continue;                    // not a press
		measure_and_show();
		while (!funDigitalRead(PC0)) Delay_Ms(10);            // wait for release
	}
}

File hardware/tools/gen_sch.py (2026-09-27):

#!/usr/bin/env python3
"""Generate hardware/dbfob.kicad_sch from the tables below.

The tables are the source of truth (etofab.md §1): hand edits to the sheet are lost on the next
run. Every symbol connects by net labels placed on its pin tips, so the drawing is a set of tidy
blocks rather than a wire diagram; UUIDs derive from the reference designator, so a re-run with
unchanged tables writes a byte-identical file.

  python3 hardware/tools/gen_sch.py && kicad-cli sch erc hardware/dbfob.kicad_sch
"""
import os, re, uuid

HERE = os.path.dirname(os.path.dirname(os.path.abspath(__file__)))
OUT = os.path.join(HERE, 'dbfob.kicad_sch')
LIB = '/usr/share/kicad/symbols'
NS = uuid.UUID('b3a0d7e2-5c1f-4e8a-9d2b-7f6e1c0a4d35')
ROOT = str(uuid.uuid5(NS, 'root'))


def uid(*k): return str(uuid.uuid5(NS, '/'.join(map(str, k))))


# ---------------------------------------------------------------------------------------------
# Parts. LCSC numbers checked against JLC's parts API on 2026-09-27; each belongs to its package
# (etofab.md §2). CH32V002/V006 were out of stock at JLC and LCSC, so U1 is loaded with the
# pin-compatible CH32V003F4P6 (same TSSOP-20 pinout, pin table checked against the V002 datasheet
# table 2-1). Swap the LCSC number when V002/V006 stock returns; the board does not change.
#
# ref: lib_id, value, footprint, LCSC, MPN, note, (x, y, rot) on the sheet, {pin: net}
# ---------------------------------------------------------------------------------------------
LED_FP = 'LED_SMD:LED_0603_1608Metric'
R_FP = 'Resistor_SMD:R_0603_1608Metric'
C_FP = 'Capacitor_SMD:C_0603_1608Metric'

PARTS = {
    'U1': ('MCU_WCH_RiscV:CH32V003FxPx', 'CH32V003F4P6', 'Package_SO:TSSOP-20_4.4x6.5mm_P0.65mm',
           'C5187096', 'CH32V003F4P6', 'drop-in: CH32V002F4P6 / CH32V006F8P6 (same TSSOP-20 pinout)',
           (127, 95, 0),
           {'9': 'VBAT', '7': 'GND',
            '15': 'MIC_CLK',     # PC5 SPI_SCK: PDM clock out
            '17': 'MIC_DATA',    # PC7 SPI_MISO: PDM data in
            '16': 'MIC_VDD',     # PC6 GPIO: mic supply, off between presses
            '20': 'LED_G',       # PD3 TIM2_CH2
            '19': 'LED_Y',       # PD2 TIM1_CH1
            '14': 'LED_O',       # PC4 TIM1_CH4
            '13': 'LED_R',       # PC3 TIM1_CH3
            '10': 'BTN',         # PC0 EXTI wake
            '12': 'LED_R_K',     # PC2 D4 cathode: low to light, high+input to sense ambient light
            '18': 'SWIO',        # PD1 programming / debug
            '2': 'TX',           # PD5 USART1_TX: dB readout for calibration
            }),
    'MK1': ('Sensor_Audio:IM69D130', 'IM69D130', 'Sensor_Audio:Infineon_PG-LLGA-5-1',
            'C536262', 'IM69D130V01XTSA1', 'bottom port: the NPTH in the footprint is the sound inlet',
            (200, 90, 0),
            {'2': 'MIC_VDD', '5': 'GND', '3': 'MIC_CLK', '1': 'MIC_DATA', '4': 'GND'}),
    'C3': ('Device:C', '100n', C_FP, 'C14663', 'CC0603KRX7R9BB104', 'mic decoupling, next to MK1',
           (220, 90, 0), {'1': 'MIC_VDD', '2': 'GND'}),
    'C1': ('Device:C', '100n', C_FP, 'C14663', 'CC0603KRX7R9BB104', 'U1 decoupling, next to pin 9',
           (95, 130, 0), {'1': 'VBAT', '2': 'GND'}),
    'C2': ('Device:C', '10u', C_FP, 'C19702', 'CL10A106KP8NNNC', 'bulk: coin cell ESR vs LED + mic current',
           (80, 130, 0), {'1': 'VBAT', '2': 'GND'}),
    'BT1': ('Device:Battery_Cell', 'CR2032', 'Battery:BatteryHolder_Keystone_3034_1x20mm',
            'C5213768', 'Keystone 3034TR', 'negative contact is the PCB pad under the cell',
            (60, 130, 0), {'1': 'VBAT', '2': 'GND'}),
    'SW1': ('Switch:SW_Push', 'measure', 'Button_Switch_SMD:SW_Push_1P1T_XKB_TS-1187A',
            'C318884', 'TS-1187A-B-A-B', 'internal pull-up on PC0',
            (200, 135, 0), {'1': 'BTN', '2': 'GND'}),
    'J1': ('Connector_Generic:Conn_01x04', 'PROG', 'Connector_PinHeader_2.54mm:PinHeader_1x04_P2.54mm_Vertical',
           '', '', 'not fitted: WCH-LinkE pogo/pins; 1 VBAT, 2 SWIO, 3 GND, 4 TX',
           (45, 95, 0), {'1': 'VBAT', '2': 'SWIO', '3': 'GND', '4': 'TX'}),
    'H1': ('Mechanical:MountingHole', 'keyring', 'MountingHole:MountingHole_3.2mm_M3',
           '', '', 'keyring hole', (240, 150, 0), {}),
}
# LED bar: four low-Vf AlInGaP/GaP parts (1.6-2.6 V) so every colour still lights on a coin cell
# near end of life; InGaN green/blue need ~3 V and would not. Deliberately dim: a club is dark and
# the bar should not light up the room. At 3.0 V the resistors cap the current at ~0.45 mA
# (2.2 k) and ~1 mA for the dimmer yellow-green (1 k); firmware PWMs well below that indoors.
# D4's cathode goes to PC2 instead of GND: reverse-biased and timed, the LED doubles as an
# ambient light sensor, so the firmware can sense dark room vs daylight without a sensor part.
LEDS = [  # ref, net, colour, LCSC, MPN, R, R LCSC, cathode net
    ('D1', 'LED_G', 'yellow-green 575nm', 'C89809', 'NCD0603C3', '1k', 'C21190', 'GND'),
    ('D2', 'LED_Y', 'yellow 590nm', 'C2287', 'KT-0603Y', '2.2k', 'C4190', 'GND'),
    ('D3', 'LED_O', 'orange 605nm', 'C111340', 'KT-0603O', '2.2k', 'C4190', 'GND'),
    ('D4', 'LED_R', 'red 625nm', 'C2286', 'KT-0603R', '2.2k', 'C4190', 'LED_R_K'),
]
for i, (d, net, col, lcsc, mpn, rv, rl, k) in enumerate(LEDS):
    x = 45 + 30 * i
    PARTS['R%d' % (i + 4)] = ('Device:R', rv, R_FP, rl, '', 'LED current', (x, 40, 0),
                              {'1': net, '2': net + '_A'})
    # Device:LED pin 1 = K, pin 2 = A
    PARTS[d] = ('Device:LED', col, LED_FP, lcsc, mpn, '', (x, 62, 90), {'2': net + '_A', '1': k})

# MIC_VDD is driven by a GPIO, which ERC cannot know: flag it rather than leave the error standing
FLAGS = {'#FLG01': ('VBAT', (60, 115)), '#FLG02': ('GND', (110, 140)), '#FLG03': ('MIC_VDD', (230, 75))}
NOCONNECT = {'U1': ['1', '3', '4', '5', '6', '8', '11']}
TEXT = [   # kept left of and above the title block (which starts at x ~177, y ~166 on A4)
    ('dbfob - keyfob sound level indicator', (20, 20), 2.5),
    ('PDM mic on SPI1: PC5 SCK -> CLK at 1.5 MHz, PC7 MISO <- DATA.', (20, 150), 1.5),
    ('Mic powered from PC6 only while measuring.', (20, 154), 1.5),
    ('LED PWM: D1 PD3 T2C2, D2 PD2 T1C1, D3 PC4 T1C4, D4 PC3 T1C3.', (20, 158), 1.5),
    ('D4 cathode on PC2 = ambient light sense.', (20, 162), 1.5),
    ('U1 fitted CH32V003F4P6; CH32V002/V006 drop-in.', (20, 166), 1.5),
    ('Remove the cell before programming through J1.', (20, 170), 1.5),
]


# ---------------------------------------------------------------------------------------------
def block(text, start):
    d = 0
    for j in range(start, len(text)):
        if text[j] == '(': d += 1
        elif text[j] == ')':
            d -= 1
            if d == 0: return text[start:j + 1]
    raise ValueError


_libs = {}
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

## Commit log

2026-09-27 docs: pick IM69D130 PDM mic + CH32V002
    Digital mic removes op-amp, gain ranging and VDD-referenced ADC drift;
    ±1 dB parts allow batch instead of per-unit calibration. AOP >= 130 dB
    SPL required so the red band doesn't clip. CH32V002 has hardware
    multiply and runs to 2.0 V; CH32V003 has neither.
2026-09-27 hardware: rev A schematic, PCB and JLC outputs
    30 x 52.5 mm, single-sided assembly: IM69D130 PDM mic, TSSOP-20 CH32
    (fitted CH32V003F4P6 - V002/V006 out of stock, same pinout), four
    low-Vf LEDs as a level bar, CR2032 in a Keystone 3034.
    Generated end to end by hardware/tools (gen_sch -> make_pcb -> fab):
    ERC clean, DRC 0 errors / 0 unconnected / 0 parity, byte-identical
    reruns. No top copper under the cell's + rim; MK1's port hole is held
    to 0.20 mm by a rule scoped to MK1 alone.
    [bom_jlc.csv, bom_manual.csv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]
2026-09-27 hardware: fix JLC placement of MK1 and BT1, verify CPL
    JLC places parts with the EasyEDA footprint of each LCSC number. Against
    those, the first CPL had MK1 turned 90 degrees (port off the sound
    hole, pins on the wrong pads) and BT1 backwards (opening facing U1, no
    cell could go in). MK1 also needs its CPL point moved 0.13 mm: EasyEDA's
    origin is not the package centre (datasheet fig. 11 matches KiCad).
    check_cpl.py now places the cached EasyEDA footprints as the CPL says
    and checks pin identity per pad, the sound-port hole and the holder
    opening; fab.py fails if it does. It flags both errors on the old CPL
    and passes all 15 placements on the new one.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
    [cpl_jlc.csv, dbfob-B_Cu.gbr, dbfob-B_Mask.gbr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]
2026-09-27 hardware: dim LED bar, D4 doubles as ambient light sensor
    Resistors 2.2k (1k for the dimmer yellow-green) cap the LEDs at
    ~0.45-1 mA; a club is dark and the bar should not light the room.
    D4's cathode moves from GND to PC2 so the red LED can be reverse-biased
    and timed as a light sensor: auto-dim indoors, brighter in daylight,
    no extra part. Rerouted: DRC/parity clean, CPL check passes.
    [bom_jlc.csv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]
2026-09-27 Show bare-ear and with-plugs verdicts together
    Either default misleads someone: assume plugs and the unprotected get a
    falsely safe answer; assume none and plug wearers always see red. Every
    reading now shows both - steady LED for a bare ear, blinking LED for
    room level minus 12 dB - so there is no mode to set or forget. Bands are
    redefined as level at the ear (G<=83 Y<=90 O<=96 R>96 dBA); back-silk
    legend updated to match. No circuit change.
    [dbfob-B_Cu.gbr, dbfob-B_Mask.gbr, dbfob-B_Paste.gbr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]
2026-09-27 Address hardware audit: clock plan, claims, power, release gates
    - PDM clock 1.024 MHz sat between the IM69D130's specified bands and
    cannot be divided from 48 MHz; now 1.5 MHz (48/32 or 24/16),
    decimated by 64 to 23,437.5 samples/s.
    - Bands restated as levels at the ear with allowance times from the
    stated curve (96 dBA = 38 min, not an hour); the plugs LED is a
    conditional estimate, not a safety verdict. Silk legend updated.
    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
    [dbfob-B_Cu.gbr, dbfob-B_Mask.gbr, dbfob-B_Paste.gbr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]
2026-09-27 docs: record prototype part choice and T5818 clock analysis
    Rev A prototype run uses CH32V003 + IM69D130 (both stocked at JLC).
    The T5818 second source needs its 2.0-3.3 MHz high-quality mode for
    135 dB AOP, which the power-of-two SPI divider reaches only at 3.0 MHz:
    twice the PDM rate, ~6% more decimator CPU by estimate, same output
    rate after /128.
2026-09-27 docs: lead-free HASL for prototypes, ENIG for production
    ENIG raised the 5-board PCBA order from 6.46 to 22 EUR for little gain
    at this pitch; the holder spring keeps the cell on a HASL pad. Lead-free
    because the boards go on keyrings. Also note JLC's in-board tooling
    holes on a fully poured 1x1 board.
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2026-09-27 firmware: CH32V003 PDM capture, A-weighting, LED verdicts, standby
    ch32fun-based firmware for the rev A board, not yet run on hardware:
    - SPI1 RX-only master at 1.5 MHz (48/32) + circular DMA; the ISR
    decimates in place (CIC-4, R=64 -> 23,437.5 S/s)
    - A-weighting as 4 first-order high-passes + 1 fitted biquad (CIC droop
    folded in), Q13 constants: within 0.02 dB of IEC 61672 50 Hz-8 kHz
    - no hardware multiplier: dsp.c at -O2 so constant multiplies become
    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
2026-09-28 case: board STEP, geometry and spec for a two-part M2 case
    Board exported as STEP with part positions, heights and holes in
    board_geometry.json, all generated from the KiCad layout. README fixes
    the case design: two shells with one M2 screw past the cell edge, open
    LED windows with light tubes, a flexure button, a keyring tube through
    case and board, and a back mic port with a gasket ring.
    [dbfob-board.step]
2026-09-28 case: parametric FreeCAD script for the two-shell M2 case
    make_case.py builds the front and back shells from board_geometry.json:
    board pocket and ledge, alignment lip (open along the cell edge),
    M2 screw end, keyring tube and bosses, LED windows with light tubes,
    button flexure with nub, and a back mic port with a gasket ring.
    It checks fit by intersecting the shells with the board and parts
    (all 0 mm^3 on rev A) and exports STEP/STL in print orientation.
    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
2026-09-28 case: rev A shells exported for printing
    Back 33.8 x 60.6 x 4.0 mm (floor down) and front 33.8 x 60.6 x 5.7 mm
    (top down), STEP and binary STL, generated by make_case.py in FreeCAD
    and checked against the desktop copies by SHA-256. No supports needed.
    [dbfob-case-back.step, dbfob-case-back.stl, dbfob-case-front.step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]
2026-09-28 case: SLA build with sealing crush bead and a safer flexure
    PROCESS switch in make_case.py: 'sla' tightens clearances (0.15 mm
    board, 0.1 mm lip and nub gap) and adds a 0.08 mm crush bead on the mic
    gasket ring so the board preloads onto it and seals the port; 'fdm'
    keeps the loose fits. The button hinge moves from 4.5 to 8 mm from the
    nub: full-travel strain drops from 2.7 % (would crack resin) to 0.66 %.
    Fit check: front vs board/parts/back 0 mm^3; back vs board exactly the
    bead's intended 0.196 mm^3. Exports are the SLA build, 33.5 x 60.45 x
    8.9 mm, hashes checked against the desktop copies.
    [dbfob-case-back.step, dbfob-case-back.stl, dbfob-case-front.step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]
2026-09-28 case: keyring to the bottom end, screw through H1 at the top
    With the keyring next to the mic port, a hand holding the fob by its
    keys covered the mic. The keyring moves to a case-only hole at the
    bottom end (Ø3.6, 2 mm web), and the screw goes through the board's own
    Ø3.2 H1 hole at the top, clamping the board between two bosses: M2 x 6
    button head, 0.8 mm counterbore, 3.6 mm engaged, tip 2.1 mm short of
    the front face. The mic port and LEDs now have the top end to
    themselves. Fit checks unchanged (only the intended crush bead).
    33.5 x 62.25 x 8.9 mm.
    [dbfob-case-back.step, dbfob-case-back.stl, dbfob-case-front.step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]
2026-09-28 case: centre the mic port
    The IM69D130's port is 0.68 mm off its package centre, so the board's
    sound hole sits at x = 14.32. The case port is now centred at x = 15.0
    and joined to the board hole by a stadium cavity inside the gasket
    (0.68 mm^3), with the wall and crush bead following it. Checked: air
    path open at every probe point, wall solid, fit unchanged apart from the
    intended bead (0.161 mm^3). Board untouched. The gasket crosses the
    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
    [dbfob-case-back.step, dbfob-case-back.stl, dbfob-case-front.step]
2026-09-28 case: straight mic port again, gasket clear of the via
    Drop the centring cavity: the port is a straight hole under the board's
    sound hole (0.68 mm off the case centreline, accepted), and the gasket
    ring shrinks to an outer radius of 1.1 mm so it clears the tented SWIO
    via by 0.11 mm - no resin dab needed. Checked: nothing of the back shell
    in the via column, air path open, wall solid, crush bead the only
    overlap with the board (0.128 mm^3).
    [dbfob-case-back.step, dbfob-case-back.stl, dbfob-case-front.step]
2026-09-28 docs: bring README up to date, drop stale roadmap
    README: a status table for hardware, firmware and case; how it works
    with the dual-verdict LED bar; the parts as built (CH32V003, not the
    out-of-stock V002) with why; a standby estimate of ~3 years instead of
    'years'; the real repository layout (hardware/case); and a Next list in
    place of the old roadmap (breadboard step skipped, case done). The
    dosimeter is marked as not implemented. mic-mcu-options: framed as a
    decision record, next steps point at rev A bring-up.
2026-10-03 firmware: printf over SWIO for bring-up, ESP32-S2 programmer docs
    make flash PRINTF=swio routes printf through the SWIO programming wire
    (ch32fun debugprintf), read with ch32fun's 'make monitor' through the
    same programmer - so the ESP32-S2 (esp32s2-funprog) both flashes the
    board and shows its output, no USB-UART needed. Normal builds keep the
    non-blocking UART on J1 T. README: J1 wiring for WCH-LinkE and
    ESP32-S2, the S2 programmer setup, and which build prints where.
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2026-10-12 dsp: fix quiet-room floor (exact squares, fractional mean square)
    Board 1 read exactly -81.2 dBFS (48.7 dBA) in every quiet room: the
    mean square energy/n was an integer, clamped to 1 LSB^2, and the
    squares were of |y|>>2. Square |y| exactly below 2^16 and keep 8
    fraction bits in the mean square; silence now reads -117 dBFS. Added
    a silence-floor test.
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2026-10-12 docs: dosimeter verified on board 1 (short test), LSI 4.4 % slow
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2026-10-12 firmware: sleep through captures, shorten timer-only wakes
    34461A profile on board 1: a 2 s dose sample cost 8.4 mA, 6.7 mA of it
    the core busy-waiting at 48 MHz; timer-only wakes were 20 ms of
    debounce. The core now sleeps between DMA interrupts while capturing,
    and a wake checks the button after 1 ms before debouncing.
2026-10-12 firmware: keep SRAM clocked in sleep during capture; print AHBPCENR
    Board 1 hung in the first sleeping capture (5.2 mA, no DMA interrupt).
    Suspect the SRAM clock is gated in sleep so DMA stalls; set SRAMEN
    explicitly and print the register at boot to confirm.
2026-10-12 firmware: back to busy-waiting during capture
    On board 1 the DMA interrupt never woke the core from WFI sleep (a
    wake counter stayed at zero), so every capture hung. Revert to the
    busy-wait and drop the diagnostics; keep the 1 ms button check on
    timer wakes.
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2026-10-12 firmware: keep the last dosimeter run in flash, decode with make dose-log
    The last 1 KB (0x08003C00) holds a header plus one byte per sample (0.5 dB
    steps, 0 = invalid) and a stop / auto-off marker, erased at each start. It is
    read through the programmer with the cell out; tools/dose_log.py prints the run
    length, LAeq, the dose and a 10-minute table. make check fails if the firmware
    grows into the log.
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2026-10-13 firmware: DIAG=1 noise-floor diagnostics (band levels, 3 MHz mic clock)
    The quiet-room floor is ~48 dBA against the mic's ~25 dBA self-noise. The
    diagnostic build measures each double click at 3 MHz and then 1.5 MHz and
    prints A-weighted levels below 8 kHz and 2 kHz plus an unweighted level, to
    tell top-band modulator hiss from anything else and to see whether a 3 MHz
    clock fits the CPU. The normal build is unchanged (shared add_sq helper only).
    Host tests cover both clocks and the band filters.
    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
2026-10-13 firmware: DIAG fixes (band filter overflow, DC tracker) and a raw spectrum dump
    Board 1 read dBA_lt8k = 131.6 every time: the mic's start-up transient overflowed
    the band filters and they never recovered. Saturate their input and output (with
    a host test of a full-scale start). The unweighted DC tracker now settles fast
    during the skip. The DIAG build also dumps raw frames at both clocks;
    tools/floor_spectrum.py turns a monitor log into octave-band levels and tones.
    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
2026-10-13 dsp: quiet-room floor from the filter arithmetic (48 -> ~39 dBA expected)
    The raw samples from board 1, filtered in float, give ~37-39 dBA in a quiet room;
    the firmware read 48. Replaying them through a model of the integer chain showed
    why: the high-pass shifts' -0.5 LSB bias (amplified ~90x by the 20.6 Hz poles,
    a -2.9 LSB DC at the output) and too few bits for a signal of a few LSB.
    - Keep 2 more CIC bits: full scale 2^18 (x = (cic - 2^23) >> 5).
    - High-pass sections as y1 + (x - x1) - y1 (8192 - P) >> 13, small products,
    with error feedback (remainder carried); rounding instead stuck at +-1 LSB.
    - Biquad in Q12 so y << 12 fits up to |y| = 2^19; plain shift there (error
    feedback limi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
2026-10-14 firmware: triple click shows the dose as a blink rate
    A single click no longer does anything, so a press in a pocket stays
    dark. A triple click shows the dose so far (bare ear): the whole bar
    blinks for 3 s with a period of 1 s at 0 % of the daily allowance,
    shrinking linearly to steadily lit at 100 %.
    A double click is now reported once no third click follows, so the spot
    check starts about 0.4 s later, with the button already released and
    its click out of the measurement.
    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
2026-10-19 firmware: print button timings with each button event
    A bench fob reports a spot check on every single click. Print the event
    and the press / gap durations the firmware measured, to tell contact
    chatter from a logic error.
    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
2026-10-19 firmware: low-battery lockout at power-on and every wake
    On the bench, 2.8 V through 47 ohm (a tired CR2032) left the fob hung at
    power-on, drawing 3-4 mA with no LEDs: it burns the rest of the cell. The
    V003 needs 2.7 V.
    At power-on and at every wake, measure VDD first, still on the 24 MHz HSI
    before the PLL. Below VBAT_LOCKOUT_MV (2.75 V) only sleep: a running
    dosimeter stops with a new low-battery end marker (0xFC) in the flash log,
    and a button press gets one short dim red blink. No printf or SysTick in
    that path. The power-on LED sweep also stops early if VDD sags under it.
    dose_log.py and log_summary.py know the new marker.
    Not yet tested on hardware.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
2026-10-19 firmware: refuse readings below 2.7 V under load, not 2.8 V
    On a 2.8 V bench supply every spot check came out invalid: the capture
    load sags VDD by ~60 mV (3326 -> 3264 at 3.3 V), below the 2.8 V limit.
    The V003 is specified from 2.7 V and the audio path is digital, so a
    reading taken above 2.7 V is good. The lockout stays at 2.75 V at light
    load.
    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
2026-10-19 firmware README: correct the lockout bench numbers (47 ohm: 2.9 V locks out, 3.0 V refused, 3.3 V measures)
    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
2026-10-19 firmware: run at 24 MHz from the HSI, without the PLL
    The capture peaks above 10 mA, which a tired CR2032 can't hold: through
    47 ohm a 3.0 V supply sags under 2.7 V while measuring. The DSP takes
    about 41 % of 48 MHz, so it should fit at 24 MHz (no flash wait state
    there). The mic clock stays 1.5 MHz (24 MHz / 16). DIAG builds keep the
    48 MHz PLL for their extra filters and the 3 MHz mic clock.
    Not yet run on hardware: check cpu= and overruns=0 first.
    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
2026-10-19 firmware: lockout reads VDD for up to ~10 ms more before believing a low value
    At 24 MHz (a28684e) a fob on 3.0 V through 47 ohm locked out, where the
    48 MHz build had passed the wake check and gone on to measure. The 1 ms
    settle loop runs faster with no flash wait state, and Vrefint, still
    settling after standby, reads VDD low. Normal wakes stay as short as
    before: the extra reads only happen when the first average is under the
    limit.
    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
2026-10-20 firmware README: the 3.0 V / 47 ohm lockout reads 2709 mV, a real sag
    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
2026-10-21 dose_log.py --svg: fit the dBA axis to the loudest sample, round dose ticks, mark 100 %
    The axis stopped at 100 dBA, so a 104 dBA sample was drawn at 100. Short runs get
    half-hour ticks, and the dose axis gets four round steps with the daily allowance dashed.
    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
2026-10-21 Dose log: flag overloaded samples with a 0xFB byte before the level
    The level of an overloaded sample is still logged and counted, as a lower bound. The flag
    costs a byte only when it happens. dose_log.py counts the overloads, marks the 10-minute
    row and draws a red dot on the graph; log_summary.py skips the flag byte.
    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
2026-10-29 docs/rev-b.md: rework after fact checks and a design review
    The nRF52833 PDM block tops out at 16 kHz and its REG0 cannot power the mic, so the
    nRF54L replaces it. Adds the EU battery removability rule (Feb 2027), the real Qi
    coupling evidence, PTX30W (Renesas), a 140 mAh cell that fits, certification costs,
    and the review's case for a simpler rev B (coin cell, NFC readout, clip) plus five
    experiments to run before any board.
    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
2026-11-03 hardware/nfc-test: NFC test board for rev B (B1), CH32L103 decided
    A 30 x 38 mm board with B1's 30 x 26 mm outline and antenna (6-turn PCB
    coil, about 2.1 uH in air), an NT3H2111 with C0G trim pads, a field LED
    on FD, and B1's CR2032 holder on the back. It ships in the same order
    as B1, so B1 copies the antenna and its trim pads, and the bench result
    sets the trim cap.
    - hardware/lib/gen_lib.py: NT3H2111 symbol, an XQFN8 footprint from
    SOT902-3, and the MYOUNG BS-08-B2AA001 holder footprint (it has its
    own - spring, so a ferrite sheet fits under the cell)
    - the coil is drawn as LA track and closed to LB by a net tie; the
    turn gap is asserted in make_pcb.py because DRC skips same-net c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
2026-11-03 CLAUDE.md: keep pm issues current (Fixes #N, labels)
2026-11-03 hardware/b1: fixes from an independent review
    Button on PA0/WKUP, wired to VBAT with no pull-up. On some CH32L103 lots
    PB13's shared CC1 pad forces a 5.1k pull-down on in Standby, which held
    the old 1M-pulled BTN low (DS table 3-8-1 note 3). R8 is gone.
    LEDs move to TIM2 CH2-4 (PA1-PA3) and TIM1 CH1 (PA8), so each has its
    own compare and none needs software PWM. A fifth programming pad brings
    out USART1 TX on PA9 for the dB stream and a UART bootloader.
    The mic moves to the top right. Its port is now 1.5 mm outside the
    cell's rim; before, it opened under the overhanging cell. C6 becomes
    1 uF, as the IM66D130M datasheet asks. The mic pads get 0.05 mm mask
    clearance so they are really NSMD.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
2026-11-10 hardware/b1: fixes from the pre-order review
    An independent review of the AAA-stick B1 and the NFC test board found
    no blockers; this addresses its should-fix items.
    - Boost loops on F.Cu: C5 moved under U3 with GND hand-drawn from pin 2
    down the channel between the pad columns and VDD round pin 4 (was
    7 mm through two vias on In2); SW hand-drawn 0.4 mm; R9/R10 in a row
    below. The router reshapes SW even when it isn't asked to route it,
    so a User.2 keepout (--keepout) clears its gap and restore_sw() puts
    the straight track back after routing.
    - C4 moved to U2's top-left with a hand feed from pin 19; VCELL to U2's
    ADC pin hand-routed through In2. Routing back to inside_out orderi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
2026-11-10 hardware/b1: Tag-Connect TC2050-IDC-NL footprint for programming
    J1's five pogo pads become KiCad's stock Tag-Connect_TC2050-IDC-NL footprint
    (2x5 at 1.27 mm, three guide holes), turned across the stick at x 63.5 so
    the guide holes land between the cell contacts. ARM Cortex 10-pin pinout:
    1 VDD, 2 SWDIO, 4 SWCLK, 6 TX (SWO slot), 3/5/9 GND; 7, 8, 10 unconnected.
    SW1 moves to x 69.5 and the board label turns across the stick before the
    keyring hole. Router keepouts clear the guide holes (the router only knows
    pad clearance); the guide holes in BT1's courtyard are whitelisted, since
    the plug's pins come out under the cell: the cell comes out to program.
    J1 is out of the BOM, matching the footp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
2026-11-11 hardware/b1: legged TC2050-IDC footprint at the very end, stick 93 mm
    The owner's Tag-Connect plug is the legged TC2050-IDC: its clips latch
    through four 2.4 mm holes from behind, so it can't sit over the cell. J1
    becomes KiCad's Tag-Connect_TC2050-IDC-FP, along the stick past the
    keyring hole, which stays 1.5 mm past the cell's + contact. The shared
    outline grows from 82.5 to 93 mm (the test board follows; nothing changes
    near its coil). The cell can now stay in while programming.
    The router knows pad clearance but not the 0.25 mm hole clearance, so J1's
    and H1's NPTH pads are grown 0.2 mm while it routes and shrunk back after
    (restore_npth). C3's GND, boxed in behind the tag's top row, ge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
2026-11-11 hardware/b1: Tag-Connect first, keyring hole at the very end, stick 94 mm
    The owner wants the keyring hole at the end: past the cell's + contact
    now comes J1 (TC2050-IDC, clip holes 1.5 mm past the contact), then H1.
    Shared outline 94 mm; the test board follows.
    Routing needed help after the swap:
    - FD joins SW as a hand net (HAND_NETS, restore_hand): drawn along the
    bottom edge as the router once had it, kept from the router and put back.
    - A VDD stub and via for J1 pin 1, boxed in by the clip and guide holes.
    - SW's router keepout widened by a via radius (the router checks via
    centres only; a SWDIO via landed in SW's gap).
    - Backward routing direction is the default now.
    Both boards: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
2026-11-14 hardware/b1: ring hole 2.7 mm, board name to the back
    H1 grows from 1.0 to 2.7 mm at (74.25, 2.25): 0.9 mm web to the side and
    to the end, 0.35 mm from the + contact's foot pad on the back, which
    sets the size (the contact's plate stands at x 71.7, clear of it). The
    front label 'dbfob B1' moves to the back silk, under the cell.
    Library footprint MountingHole_2.7mm replaces the 1.0 mm one.
    DRC clean, two runs byte-identical.
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

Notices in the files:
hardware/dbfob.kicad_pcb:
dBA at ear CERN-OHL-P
